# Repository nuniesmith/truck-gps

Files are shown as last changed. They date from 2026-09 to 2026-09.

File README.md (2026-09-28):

# Truck GPS mount and controller

A parametric Garmin OTR620 mount for the upper cubby of a **2022 Volvo VNL 860**, printed on an **Ender 3 Neo with a 220 × 220 mm bed**.

**Current print checkpoint: [v0.6 caliper fit tests](src/stl/v0.6/README.md).** The user confirmed a **170 mm clear inside width, 98 mm front height and 80 mm height below the rear notch**, plus cased AirPods measuring **64 x 49 x 24 mm**. Four updated coupons test these dimensions. **The v0.5 full insert and rear electronics layout need revision before printing:** its fan and carrier exceed the newly confirmed rear height. The complete electronics prototype remains archived in [v0.5](src/stl/v0.5/README.md).

The controller plan is now **Pico first, Linux Zero later**. This supersedes the earlier Zero-only control plan. `src/pi/` remains a simulation-only Python package; it has no live GPIO, Pico firmware, working power distribution or telemetry integration.

## Start here

- [Current fit coupons and measurement review](src/stl/v0.6/README.md)
- [Previous electronics prototype and assembly](src/stl/v0.5/README.md)
- [Hardware choices, fan variant and power architecture](docs/hardware-v0.5.md)
- [Complete staged parts list](docs/parts-list.md)
- [Current tasks and measurements](docs/todo.md)
- [Pico and future Linux implementation plan](docs/pi-setup.md)
- [Run the existing controller simulation](src/pi/README.md)
- [Recorded v0.2 truck tests](docs/fit-test-v0.2.md)
- [Conversation archive](docs/chats.md) and [v0.5 decision record](docs/decisions-v0.5.md)

## What has been checked physically

The user reports that the original front test frame fits, the 7 mm dash-bolt shank passage works, and the AirPods Pro 3 with Latercase fit snugly in the collar. The earlier **rear +10 mm** correction was implemented in v0.4/v0.5, but is now superseded by the confirmed **80 mm height below the rear notch**. The v0.6 gauges use the new measurements and have not yet been physically tested. The original bolt-head pocket was too tight; the current **10.8 mm** pocket remains a trial until a sizing coupon is selected. The existing ball mount will be removed. The rubber cubby liner may be removed if needed for seating.

No physical fit is claimed for the new fan, complete Pico stack, ESR recess, control pod, future Zero module, GPS bezel or angled GPS cable. Mesh validity and nominal CAD clearance are distinct from these tests.

## Mechanical layout

The following describes the previous prototype; its rear packing is pending revision.

| Area | v0.5 provision |
|---|---|
| Main cubby | Fan on the driver's-view left; Pico/Freenove carrier on the right; existing dash-bolt columns retained |
| GPS front | Removable gasketed faceplate using four ordered M2 × 6 screws and plain nuts |
| Ventilation | Lower speaker/intake slots and a matching-style upper exhaust row; microphone clearance retained |
| AirPods side | Tested collar section, front facing up at 45°, with bottom USB-C cable access |
| PopSocket side | Flat storage face with a trial recessed ESR target ring; no charging |
| Shelf underside | Removable future Pi Zero 2 W module and separate universal power module |
| Optional left pod | Replaceable blank front for a selected OLED and switches |
| Power inlet | Replaceable blank panel; USB-C hardware still to be selected |

The upper border cannot accommodate the full lower-slot height. Its shorter vents and shallow fan plenum need an airflow/noise test. No cooling performance is guaranteed by the CAD. The optional control pod and populated shelf need a radio/trim clearance check in the truck.

## Controllers and power

The **Pico 2 WH** will handle the local fan, temperature sensor, dim blue LEDs, buttons and display. The future **Pi Zero 2 W**, running a full OS, can provide network access, logging, maps and other services. Basic cooling must continue if that computer or its network connection fails.

The Pico sends control signals; a separate protected power circuit supplies the load current. Initially keep the Garmin on its supplied/approved power arrangement and power the accessories separately. The earlier 5 V / 1 A GPS estimate is unverified. A combined USB-C input requires a selected sink/PD design, rated regulation, protected outputs and proper USB-C charging-port behavior. A bare socket or splitter is insufficient. The Linux computer also needs a defined shutdown/power-hold arrangement.

**Fan selection:** use the exact **NF-A4x20 5V PWM** model. The recently linked B072Q3CMRW is the three-pin 5 V variant; the earlier B071W93333 is 12 V PWM. The final user decision is four-pin PWM at 5 V. See the [manufacturer-backed connection plan](docs/hardware-v0.5.md#fan-wiring-and-behavior).

## Revision history

| Directory | Role |
|---|---|
| [v0.1](src/stl/v0.1) | First Claude design and tests |
| [v0.2](src/stl/v0.2) | Rubber pads and accessory shelf; user's first reported fit tests |
| [v0.3](src/stl/v0.3) | ChatGPT V3.1 faceplate, M2 hardware and coupons |
| [v0.4](src/stl/v0.4) | Measured rear +10 mm, bolt-head coupons and wired AirPods shelf |
| [v0.5](src/stl/v0.5) | Previous electronics prototype; rear height superseded |
| [v0.6](src/stl/v0.6) | Four caliper-based fit coupons; full enclosure revision pending |

Older revisions and transcripts are preserved. The `v0.3` folder contains the CAD revision named V3.1; older `src/v0.x` paths and repository names in the archive are historical.

## Future software

The Linux simulation in `src/pi/` implements fan hysteresis, auto/boost policy, LED requests, typed sensor faults and text/JSON status. It does not operate physical hardware. A Pico firmware project and a bounded Pico-to-Pi protocol remain to be implemented. See [the implementation plan](docs/pi-setup.md).

Later goals include truck Wi-Fi/Starlink connectivity, a private Tailscale connection to a home display, trip history and a map. A live Garmin position interface has not been established; a separate GNSS receiver may be needed. Neither selected board has built-in GNSS. The existing [TomTom](docs/tomtom-api.md) and [Google Maps](docs/google-maps-api.md) notes are planning references; recheck terms and pricing when implementing those services.

Repository: [nuniesmith/truck-gps](https://github.com/nuniesmith/truck-gps).

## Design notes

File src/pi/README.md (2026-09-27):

# Truck GPS controller: simulation milestone

> **v0.5 architecture update:** the Pico 2 WH is now planned for local hardware control; a Pi Zero 2 W will add Linux services later. This package remains a simulation and is not Pico firmware. Follow [the current implementation plan](../../docs/pi-setup.md) and [hardware decisions](../../docs/hardware-v0.5.md). Earlier Pi-only hardware suggestions below are superseded.

Runnable control logic for the planned **Raspberry Pi Zero 2 W / Raspberry Pi OS Lite** installation. Requires Python **3.11 or newer** and has no runtime dependencies outside the standard library. GPIO, physical sensors, fan PWM, buttons, OLED, GPS power switching and telemetry are **not implemented**. The only supported mode is `simulate`.

## Run now, without Pi hardware

From the repository root:

```sh
cd src/pi
python3 -m truck_gps --config config.example.toml
python3 -m truck_gps --config config.example.toml --format json
python3 -m unittest discover -s tests -v
```

The built-in 12-sample demo completes immediately. Each sample advances a virtual clock by five seconds. Use `--realtime` to pace samples in wall-clock time, or `--realtime --loop` for a continuous demonstration. The timestamps still represent **scenario time**, not measured sensor acquisition time. Ctrl+C or SIGTERM interrupts the wait and exits cleanly.

For an installed command, use a virtual environment:

```sh
python3 -m venv .venv
.venv/bin/python -m pip install .
.venv/bin/truck-gps --format json
```

Building the package requires setuptools; pip may download the build tooling. No Raspberry Pi or GPIO packages are needed for simulation. Keep local settings in `config.local.toml` (ignored by git); do not put credentials in configuration files committed to the repository.

## Control behavior

These values are **bench starting settings**, not validated GPS/charger protection limits. Adjust only after choosing sensor placement and measuring the actual installation.

| Condition | Requested fan duty with the example configuration |
|---|---|
| Fresh startup, valid temperature below 35°C | 0% |
| Temperature reaches 35°C | 30% |
| Temperature rises from 35°C to 45°C | Linear increase from 30% to 100% |
| Temperature at or above 45°C | 100% |
| Active fan cools below 35°C but remains above 32°C | Hold 30% |
| Temperature reaches 32°C or lower | 0% |
| Manual `boost` | 100% |
| Missing, invalid, wrong-ID or stale sensor reading | 100% and an explicit fault |

A reading becomes stale when its age **exceeds** 15 seconds. A future or invalid timestamp is a fault. Sensor faults take priority over manual mode. There is deliberately no manual force-off mode. After a fault or boost, automatic control keeps the fan active until the stop threshold is reached. Restarting the process resets the hysteresis latch and command state; it does not preserve settings from earlier runs.

The 30% minimum is a requested value, not a verified starting or sustainable fan speed. Startup kick, calibrated minimum duty, electrical fallback and measured RPM remain hardware work. A software request for full cooling cannot guarantee cooling if the fan supply or controller fails.

LEDs default off with a stored brightness of 5%. Turning them off preserves the setting. LED commands do not affect fan decisions. `--led-on`, `--led-brightness 8` and `--fan-mode boost` set **initial** commands; later scenario events can change them. Brightness alone does not enable the LEDs. In particular, the built-in demo intentionally changes LED and fan modes.

## Custom scenarios

```sh
python3 -m truck_gps --scenario scenarios/example.json --format json
```

A scenario is a JSON array. Each row must contain exactly one sample source:

- `"temperature_c": 40` for a valid numeric reading, or `null` for a missing sensor.
- `"error": "disconnected"` for a reported sensor fault.
- `"w1_text": "aa YES\naa t=35000"` to exercise parsing of a captured Linux 1-Wire text sample.

Optional fields are `age_s` (default 0), `fan_mode` (`auto` or `boost`), `led_enabled` (boolean) and `led_brightness_pct` (0–100). Command changes persist into following rows until changed again. A repeated scenario retains command and hysteresis state across the loop boundary. Temperature/source and age apply to their own row only. Unknown keys, non-finite numbers, invalid commands and malformed configuration are rejected before the simulation starts. Out-of-range finite temperatures are accepted as scenario inputs and become controller faults.

The 1-Wire parser checks the kernel's `YES` CRC result marker and temperature format. It does not independently calculate CRC or read `/sys`. There are no device reads or retry loops yet; bounded acquisition and freshness tracking must be implemented for live sensors.

## Output and verification

Text output labels all values as requests. `--format json` emits one status object per line to stdout, with logs on stderr. `simulated` is always `true`; `fan_rpm` and `gps_power` are always `null` (unknown). No RPM, GPS state or power feedback is invented. `sensor_id` identifies the configured expected sensor, not necessarily a connected device.

All 21 tests passed on Linux with Python 3.12.14. Wheel building, installation into a clean virtual environment and the installed CLI demo also passed. Tests cover the fan curve and hysteresis, fault priority/recovery, stale boundaries, malformed readings, configuration validation, LED independence, restart state, CLI output and SIGTERM handling. They verify software decisions only. No physical fan, sensor, OLED, GPIO timing or Raspberry Pi installation has been tested.

## Optional Linux service example

[`systemd/truck-gps-sim.service`](systemd/truck-gps-sim.service) is a **simulation-only template**, not a production cooling service. It loops the demo and logs JSON to the journal. To use it later, install the package in `/opt/truck-gps/.venv`, copy settings to `/etc/truck-gps/config.toml`, create a dedicated `truck-gps` service account with read access to those paths, and install the unit in `/etc/systemd/system/`. Then reload systemd and start `truck-gps-sim.service`; enable boot startup only if wanted. Use `journalctl -u truck-gps-sim.service` to inspect output.

The template deliberately denies device access. Do not adapt it for live hardware merely by removing that restriction: implement and test the GPIO/sensor adapters and their permissions first. Neither this unit nor a restart policy provides an electrical cooling fallback or a Linux power-hold/shutdown circuit.

## Next implementation work

1. Record the installed Pi OS/Python versions and verify hardware PWM support for that board/OS.
2. Select the fan interface and validate the protected 5 V branch, PWM waveform and boot/crash state on the bench.
3. Add identified live temperature sensors with bounded acquisition and stale-data handling independent of control ticks.
4. Add fan/LED adapters, debounced buttons and optional tach feedback, then an OLED using shared state.
5. Validate systemd permissions, restart and power-hold/shutdown behavior before installation in the truck.
6. Add independent GNSS logging, Tailscale and the home map later.

See [the hardware and first-boot plan](../../docs/pi-setup.md) and [the project tasks](../../docs/todo.md). The Garmin initially stays on its supplied power arrangement. v0.4 CAD awaits fit results and actual component measurements.

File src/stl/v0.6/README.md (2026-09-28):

# v0.6 — caliper fit checkpoint

**Print these four test pieces next. This is not a complete enclosure revision.**
The confirmed inside dimensions supersede the v0.4/v0.5 rear +10 mm correction.
Do not print the v0.5 full insert, carrier or packing test for the newly measured cubby.
The existing electronics layout needs a separate revision after these gauges fit.

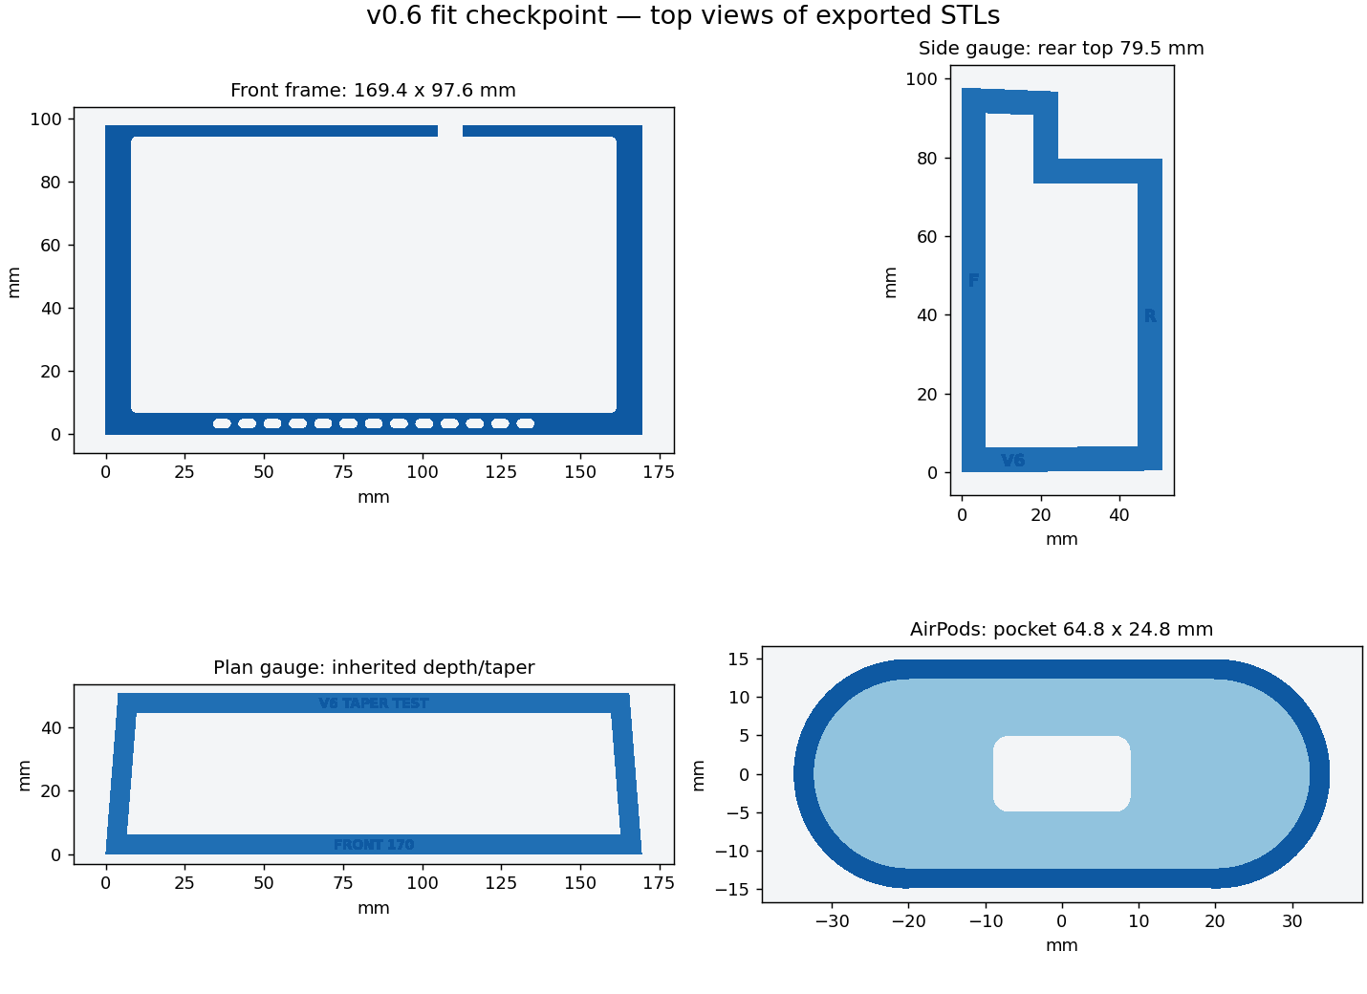
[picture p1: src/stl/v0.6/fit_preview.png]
Top views of exported test pieces


## Confirmed user measurements

Recorded 2026-09-27 (America/New_York), from the caliper sketch and follow-up replies.

| Feature | Measurement | Coupon geometry |
|---|---:|---:|
| Clear inside front width | 170 mm | 169.4 mm, 0.3 mm clearance each side |
| Front opening height | 98 mm | 97.6 mm, 0.4 mm top clearance |
| Height below rear notch | 80 mm | Rear top 79.5 mm above front-floor datum |
| AirPods + Latercase width | 64 mm | Pocket width 64.8 mm |
| AirPods + Latercase thickness | 24 mm | Pocket thickness 24.8 mm |
| AirPods + Latercase height | 49 mm | Reference for next shelf layout; collar height stays 12 mm |

The notebook's 80 mm label is a height, not depth. The user explicitly confirmed
170 mm is the inside width. These are reported measurements, not measurements
independently taken by the CAD author.

The old width input was 165.1 mm, giving a 164.5 mm printed frame. The new frame
is 4.9 mm wider. Do not scale the old STLs in the slicer: that would change the
GPS pocket, bolt holes and component footprints too.

## Print and test

Print at **100% scale**, in the supplied flat orientation. Each piece fits a
220 x 220 mm bed with a nominal 10 mm brim allowance per side. No designed
unsupported roofs occur in these coupons; inspect your slicer preview.

1. **front_frame.stl** — 169.4 x 97.6 x 4 mm. Check seating across the full
   opening without forcing. Its GPS pocket is the inherited nominal
   153.8 x 87.8 mm with 2 mm corners, microphone notch and lower grille.
   This checks the cubby face, not the actual GPS, faceplate screws or top vents.
2. **side_gauge.stl** — 50.8 mm deep x 97.6 mm high, 3 mm thick plus labels.
   The **F** edge faces the driver; **R** goes to the back. Seat the bottom on
   the same floor/liner datum used for the measurement. The notch starts
   24.4 mm behind the front; the rear top is flat at 79.5 mm. Check each side
   of the cubby independently, including the rubber lip. Record whether the
   liner is in or out; do not pull a binding gauge into place with bolts.
3. **plan_gauge.stl** — checks front width, 50.8 mm depth and the inherited
   4 mm-per-side taper (161.4 mm wide at the back). FRONT faces the driver.
   This taper is still a photo-based assumption; report any side interference.
4. **airpods_charge_test.stl** — enlarged 64.8 x 24.8 mm pocket, 12 mm collar,
   2.5 mm floor. Compare against the previously snug collar. Test retention,
   removal and your actual angled cable through the provisional 18 x 10 mm
   bottom opening. A physical pass is needed: the caliper maximum may occur
   above the section gripped by this shallow collar.

The 25.4 mm bar depth, 50.8 mm total depth, 1 mm upper-roof drop and 0.5 mm
rear-floor rise are inherited assumptions, not new measurements. Unlike v0.5,
the rear ceiling in this test is flat: the single confirmed 80 mm height does
not establish an underside slope. The gauge is intended to resolve this fit.

## Electronics review

The old layout does not fit the new height as drawn:

| v0.5 feature | Highest Y above front floor | Comparison with 80 mm rear clearance |
|---|---:|---|
| Fan body/pads | 82.0 mm | 2.0 mm too high |
| Rear carrier rectangle | 86.2 mm | 6.2 mm too high |
| Upper carrier boss envelope | 86.0 mm | 6.0 mm too high |
| Freenove PCB outline | 76.0 mm | Outline alone is below ceiling; mounting/wires still need rework |

The fan remains 40 x 40 x 20 mm (22 mm with pads), four-pin **5 V PWM**.
The control architecture remains Pico 2 WH/Freenove first, Pi Zero 2 W later.
A possible next layout lowers the fan center from Y=62 to Y=56 and the PCB
origin from Y=19 to Y=12; these are proposals only, not validated mounts.
The carrier, bosses, plenum, wiring and shell must be redesigned together and
checked against the actual stepped cubby envelope. Nothing in this checkpoint
claims that the complete assembly or airflow is validated.

## Reproduce

```sh
python export_models.py
python validate_meshes.py
```

OpenSCAD is required for exports and NumPy for validation. `mesh_checks.json`
records watertight oriented edges, triangle validity, connected components and
bed bounds. It does not certify strength, cooling, physical fit or GPS retention.
`fit_check.scad` is standalone; it deliberately provides no full insert export.

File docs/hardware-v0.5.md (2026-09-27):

# v0.5 hardware decisions and electrical plan

Updated 2026-09-27. This is a mechanical prototype and an electrical design plan. There is no completed power-distribution circuit or Pico firmware in this revision. [Print instructions](../src/stl/v0.5/README.md) · [Parts](parts-list.md) · [Software plan](pi-setup.md)

## Selected parts

| Function | Selection | CAD basis / status |
|---|---|---|
| Fan | **Noctua NF-A4x20 5V PWM, four-pin** | 40 × 40 × 20 mm body; **22 mm with pads**; **32 × 32 mm** screw pattern |
| Local controller | **Raspberry Pi Pico 2 WH** | Header-equipped Pico 2 W; mounted using the Freenove board |
| Breakout | **Freenove FNK0081 / CB8101** | **63 × 57 mm**, **58 × 52 mm** mounting pattern from its mechanical drawing |
| Future Linux computer | **Raspberry Pi Zero 2 W** | 65 × 30 mm board; 58 × 23 mm mounting pattern; under the AirPods side of the shelf |
| PopSocket target | **ESR HaloLock Universal Ring 360**, linked ASIN B09BZ17JM7 | Ordered; exact ring and adhesive thickness not measured. CAD recess is a trial |
| Faceplate | Four **M2 × 6 mm** machine screws with plain M2 nuts | Ordered; test actual screw heads and nuts in the supplied coupons |

The final fan choice supersedes both earlier Amazon links: **B071W93333 is the 12 V PWM version; B072Q3CMRW is the three-pin 5 V version.** Neither is the final requested combination. Order by the exact name **NF-A4x20 5V PWM** and verify four pins and 5 V on the label. No unverified replacement ASIN is supplied here.

The other user-supplied links were [Pico 2 WH](https://www.amazon.ca/gp/product/B0FC2QLC17), [Freenove breakout](https://www.amazon.ca/gp/product/B0BFB53Y2N), and [ESR ring](https://www.amazon.ca/dp/B09BZ17JM7). Retail package dimensions are not final part measurements.

## Physical arrangement

- **Inside the cubby:** fan on the driver's-view left, Freenove/Pico assembly on the right. The breakout attaches to a removable rear carrier. Existing dash bolt columns and the shelf's two mounting tongues remain.
- **Under the shelf:** a removable Zero 2 W module on the AirPods side and a separate module for a future selected power board on the PopSocket side. The power module has tie slots and a replaceable blank inlet panel; it does not assume a particular PD/regulator board.
- **Beside the front frame:** an optional control pod with a replaceable blank face for the eventual display and switches. Its outside edge is 42 mm left of the original insert. Verify clearance to truck trim before printing the whole pod.
- **AirPods:** retain the successful collar section and upward-facing 45° orientation, with the v0.4 bottom cable opening. No wireless charger is included.
- **PopSocket:** remove the raised oval rim and use a shallow circular recess for the ESR target. The PopSocket supplies the magnetic attraction. This is storage, with no charging electronics.

The Freenove PCB dimensions are verified, but its assembled height with the Pico, headers and wiring is not. The CAD reserves **21 mm forward from the breakout PCB back face**. Measure that complete stack. Programming USB access is a bench operation with the carrier removed; a plugged-in USB cable has not been shown to fit beside the board inside the cubby.

The future Zero module reserves a board/component envelope, not every header, heatsink or cable variant. Orient and measure connectors before installing it. Neither the Pico nor the Zero includes a GNSS receiver. Live navigation data from the Garmin has not been established; the Linux mapping project may require a separate receiver.

## Airflow and lighting

The proposed fan direction draws from the rear electronics bay and blows forward into a shallow plenum that turns upward. Lower sound slots admit air; the new upper slots exhaust it. The upper slots share the lower grille's capsule shape and pitch but are shorter because the upper frame is thin. Slots around the microphone are omitted.

This is a restricted path: the fan has about **2.4 mm** rear intake clearance; the upper riser narrows to **1.8 mm** in depth. These are CAD clearances, not proof of useful cooling. Bench-test temperature, airflow, whistling and audible GPS instructions. Speaker and fan air share the lower bay, so acoustic isolation is not claimed. If the flow is inadequate, use a larger external vent/plenum or relocate the fan before relying on cooling. The shell is not airtight, and small screw-access openings allow leakage.

Two dim blue LEDs can use the loose printed carrier and the rear carrier's tie slots. Position the LEDs against an internal surface to avoid direct glare; add current limiting and a suitable driver. The carrier's 3.3 mm bores are trial fits for nominal 3 mm LEDs. Secure insulated wires away from the impeller and the microphone path. A separate tie provision can retain a temperature-probe lead; probe shape is not finalized.

## Power architecture

The **Pico makes control decisions**. A separate rated circuit supplies the GPS, fan, LEDs, charging port and future Zero. The Freenove board is a GPIO breakout, not a multi-amp power-distribution device. Do not route accessory load current through GPIO or the Pico's 3.3 V rail.

For initial use, retain the Garmin's supplied/approved power arrangement and give the accessories a separate regulated 5 V supply. Verify the GPS and adapter labels and actual demand; **5 V / 1 A is not a confirmed GPS rating**.

For a later single-input system, select the USB-C sink/PD hardware, converter, protected outputs and connectors together. A plain USB-C socket or splitter is insufficient. USB-C charging outputs need the appropriate source/CC behavior for C-to-C cables. Match the negotiated input, output current, protection and thermal capacity to measured loads. Do not assume all USB-C PD sources offer 12 V.

The future power module's empty space is about **64 × 38 × 15 mm**, reduced by posts and the inlet bosses. Select a circuit that actually fits or replace that module. A protected external power unit remains an option without changing the GPS insert.

A capacitor can help with supply transients; it does not replace a power supply or implement lighting control. A Linux shutdown needs a defined hold-up/power-latch arrangement if ignition or a master switch removes its supply. The Pico can request shutdown and operate a properly rated load switch after an acknowledgment, but power switching hardware is still to be designed. Prevent USB/programming-supply backfeed using the Pico manufacturer's power arrangements.

## Fan wiring and behavior

| Pin | Noctua wire colour | Planned function |
|---|---|---|
| 1 | Black | Common ground |
| 2 | Yellow | Regulated protected 5 V branch |
| 3 | Green | Tachometer input with a suitable 3.3 V interface |
| 4 | Blue | PWM signal through a compatible driver/interface |

Keep fan power continuous during speed control. Nominal maximum fan load is 0.1 A at 5 V. Verify connector orientation; other fan variants have different wire colours.

Use the Pico's hardware PWM at a 25 kHz target. Noctua's white paper recommends a CMOS-style driving circuit and does **not** recommend open-collector PWM drive. Its PWM input has an internal pull-up, which must be checked for compatibility with the Pico's 3.3 V pins and unpowered state. Select and bench-test the interface rather than copying a generic PC-fan diagram. The tach output is a separate open-collector signal, with two pulses per revolution.

With PWM disconnected, the fan normally runs at full speed. That does not cover a controller fault that holds PWM low. Verify boot, reset, disconnected sensor, stalled fan, missing host and driver faults. A software watchdog alone does not establish a hardware fail-safe.

## Sources checked for this revision

- [Noctua NF-A4x20 5V PWM specifications](https://www.noctua.at/en/products/nf-a4x20-5v-pwm/specifications)
- [Noctua three-pin 5 V specifications](https://www.noctua.at/en/products/nf-a4x20-5v/specifications)
- [Noctua PWM specification white paper](https://noctua.at/pub/media/wysiwyg/Noctua_PWM_specifications_white_paper.pdf)
- [Raspberry Pi Pico 2 W datasheet](https://datasheets.raspberrypi.com/picow/pico-2-w-datasheet.pdf)
- [Freenove FNK0081 product](https://store.freenove.com/products/fnk0081) and [CB8101 drawing v1.1](https://github.com/Freenove/Freenove_Breakout_Board_for_Raspberry_Pi_Pico/blob/master/CB8101_mechanical-drawing_v1.1_20240326.pdf)
- [Raspberry Pi Zero 2 W](https://www.raspberrypi.com/products/raspberry-pi-zero-2-w/) and [mechanical product brief](https://datasheets.raspberrypi.com/rpizero2/raspberry-pi-zero-2-w-product-brief.pdf)
- [ESR HaloLock Universal Ring 360](https://www.esrtech.com/en-ca/products/halolock-universal-ring-360-black-2-pack)

The layout and clearances are this project's design decisions. They have not been certified by the component manufacturers or physically validated in the truck.

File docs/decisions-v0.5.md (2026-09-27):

# v0.5 request and decision record

Date: 2026-09-24. This is a concise decision record, not a reconstructed verbatim transcript of missing assistant turns. Earlier session text remains in [chats.md](chats.md).

The user asked to support a 40 × 40 × 20 mm fan, a Pico 2 WH microcontroller and, if practical, a future full-OS computer. They requested provisions for switches, a screen, temperature sensing, blue LEDs, USB-C intake/power distribution, the GPS and the future computer. The intended full-OS board is documented as Raspberry Pi Zero 2 W, distinct from the Pico.

They supplied Amazon links B071W93333, B0FC2QLC17, B0BFB53Y2N and B09BZ17JM7, asked for a flush recess for the ordered ESR ring, matching top/bottom vent styling, a faceplate and further test prints. They ordered M2 × 6 screws with nuts for the faceplate and expect the GPS in the next few weeks.

The later fan message was: “use this fan the 5v one”, linking B072Q3CMRW. That is the three-pin model. After the distinction was explained, the final user choice was: **“Yeah I want 4 pin pwm 5v”**. The active selection is therefore **Noctua NF-A4x20 5V PWM**, not either earlier incompatible fan variant.

Design decisions in this revision:

- Preserve the measured front fit, rear +10 mm, passing bolt-shank bore and snug AirPods collar section.
- Keep the head pocket, GPS envelope, ring dimensions and full electronics stack provisional until measured.
- Put the fan and Pico/Freenove inside the cubby; reserve separate shelf modules for future Zero and power circuitry.
- Keep control and inlet panels replaceable and blank until exact modules are selected.
- Use the Pico for local control and separate rated hardware for power delivery. Add Linux features later.
- Treat the airflow layout, PCB packing and screw stacks as prototypes requiring the supplied fit tests.

These choices are implemented in [v0.5](../src/stl/v0.5/README.md); the electrical circuit and firmware are not implemented by the CAD work.

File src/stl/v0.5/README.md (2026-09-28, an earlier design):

> **Fit dimensions superseded:** use the [v0.6 caliper fit checkpoint](../v0.6/README.md) next. Confirmed inside dimensions are 170 mm wide, 98 mm front height and 80 mm below the rear notch. This revision's full insert, carrier and packing test exceed the corrected rear clearance; do not print them as the current fit. Original documentation below is historical.

# v0.5 — electronics and modular shelf prototype

**Status: fit-test prototype, not the final long-print release.** The actual GPS, complete Pico/breakout stack, ESR ring and cable envelopes still need measurement. Editable source: [otr620_vnl_v0_5.scad](otr620_vnl_v0_5.scad). [Hardware decisions](../../../docs/hardware-v0.5.md) · [Parts list](../../../docs/parts-list.md)

This revision preserves the v0.4 front opening, measured rear-step rise, bolt-shank bores and successful AirPods collar section. It adds a Noctua **NF-A4x20 5V PWM** mount, a removable Freenove/Pico carrier, top vents, a trial ESR recess, an optional control pod and two removable shelf modules. The future computer is **Raspberry Pi Zero 2 W**, distinct from the Pico microcontroller.

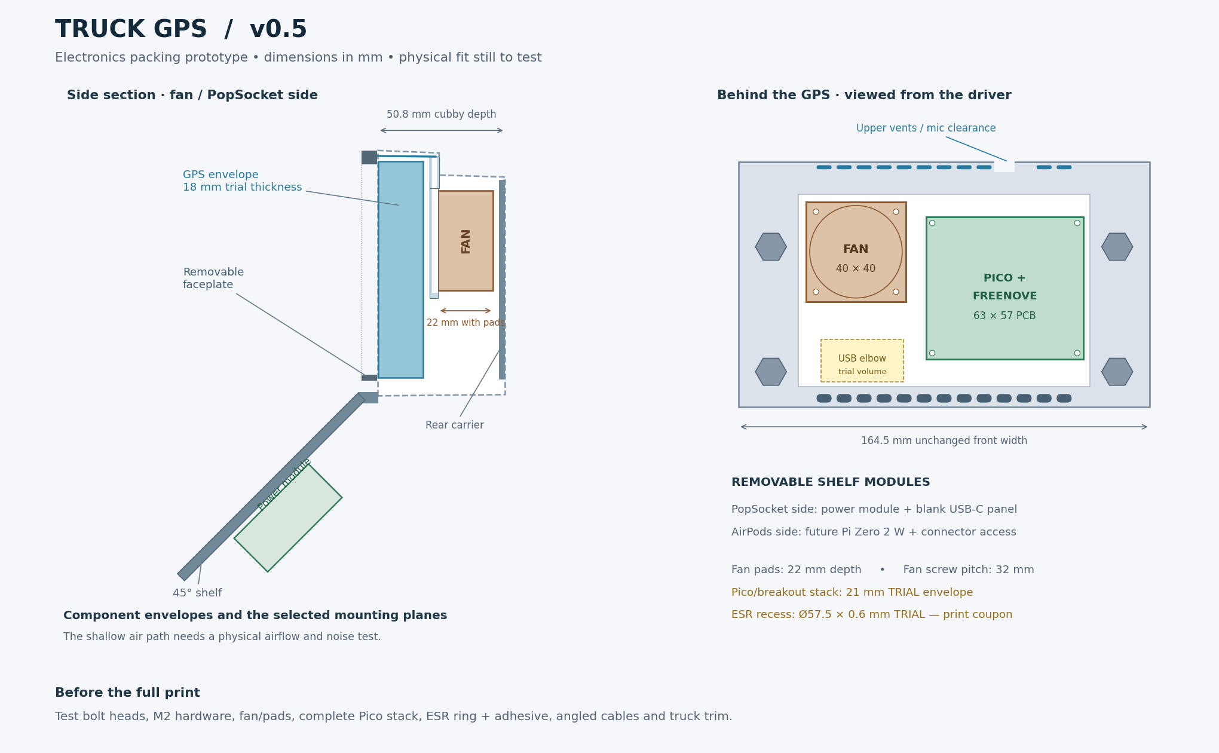
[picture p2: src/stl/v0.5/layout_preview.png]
Default component packing, with trial dimensions identified


## Print queue

Print at 100% in millimetres. These are tests, not an instruction to print all 22 files immediately.

| Order | Files | What to establish |
|---|---|---|
| 1 | `side_gauge_plus10.stl`, `bolt_head_fit_test.stl` | Confirm the measured rear rise; choose the smallest head pocket that seats the actual bolt without force. Retained unchanged from v0.4 |
| 2 | `airpods_charge_test.stl` | Confirm the tested collar with the actual angled charging cable through the bottom opening. Retained from v0.4 |
| 3 | `nut_test.stl`, `bolt_cover_test.stl` | Fit the ordered M2 nuts/screws and verify the 6 mm faceplate screw stack. Nut choices are 4.1 / 4.3 / 4.5 mm across flats, left to right |
| 4 | `fan_mount_test.stl`, `rear_carrier.stl` | Check fan hole pattern, pad stack, mounting hardware, Freenove holes and the installed Pico/header height |
| 5 | `ring_depth_test.stl` | Four **57.5 mm diameter trial recesses**, labelled 0.4 / 0.6 / 0.8 / 1.0 mm deep. Test with the adhesive included; do not glue the ring into a coupon |
| 6 | `fan_plenum_print_test.stl` | Cropped fan plenum/header in the insert's print direction; tune bridges and prove support removal before the long insert. This is not a complete airflow fixture |
| 7 | `packing_test.stl`, `control_outline_test.stl` | Check electronics packing and left-side trim space. These are alignment/layout gauges, not a substitute for the actual assembly |
| Later | Main insert, faceplate, shelf and optional module bodies/covers | Only after affected tests pass and the Garmin's fit and cable route are confirmed |

Use `packing_test` together with the known front/back cubby references. Its flat base represents the rear plane; towers extend toward the GPS. The fan tower includes its rear gap (26.8 mm total), and the Pico tower represents the provisional 29.4 mm reach from the rear plane. Neither tower is a functional electronics holder. Remove the existing ball mount for the final installation. If the rubber lip prevents seating, remove or adjust it; do not pull a distorted print into shape with bolts.

## Printable parts and OpenSCAD selectors

| STL filename | `part` selector | Role |
|---|---|---|
| `insert_v5.stl` | `insert_v5` | Main body, fan frame/plenum, top ventilation and control-pod mounting tabs |
| `faceplate_v5.stl` | `faceplate_v5` | Removable gasketed bezel, M2 × 6 hardware, matching upper vents |
| `shelf_v5.stl` | `shelf_v5` | AirPods collar, ESR trial recess and module mounting points |
| `rear_carrier.stl` | `rear_carrier` | Freenove standoffs, GPS cable opening, LED and cable tie points |
| `control_pod.stl` | `control_pod` | Optional left-side controls housing |
| `control_panel.stl` | `control_panel` | Replaceable blank for a selected screen/switch layout |
| `zero_tray.stl`, `zero_cover.stl` | `zero_tray`, `zero_cover` | Reserved future Zero 2 W module with board posts and connector windows |
| `power_tray.stl`, `power_cover.stl` | `power_tray`, `power_cover` | Universal tie-grid module; power circuitry not selected |
| `power_inlet_panel.stl` | `power_inlet_panel` | Replaceable blank for the eventual USB-C inlet/module |
| `led_carrier.stl` | `led_carrier` | Two nominal 3 mm LEDs; tie to the rear carrier after checking placement |
| `fan_plenum_print_test.stl` | `fan_plenum_print_test` | Short print to assess the new internal bridges and removable supports |
| `fan_mount_test.stl` | `fan_mount_test` | Fan screw and pad-stack test |
| `ring_depth_test.stl` | `ring_depth_test` | Four ESR recess depth tests |
| `packing_test.stl` | `packing_test` | Fan/Pico packing envelope gauge |
| `control_outline_test.stl` | `control_outline_test` | Thin control-pod trim-space gauge |
| `nut_test.stl`, `bolt_cover_test.stl` | `nut_test`, `bolt_cover_test` | M2 faceplate hardware tests |
| `side_gauge_plus10.stl` | `side_gauge` | Retained v0.4 rear +10 mm gauge |
| `bolt_head_fit_test.stl` | `bolt_head_coupon` | Retained six head-size tests |
| `airpods_charge_test.stl` | `airpods_charge_test` | Retained cased-AirPods charging-hole test |

The source is standalone. Legacy v2–v4 helpers remain for traceability; active v0.5 modules and dispatch are at the end. `part="assembly"` is a non-printing preview containing dimensional stand-ins. The top-bar, cubby, GPS and unselected electronics dimensions are assumptions except where recorded as measured.

## Dimensions that must be chosen before long prints

| Parameter | Supplied value | Basis |
|---|---:|---|
| `rear_step_raise` | 10 mm | User measured; front geometry unchanged |
| `head_af` | **10.8 mm trial** | v0.2 head was too tight; choose from the six coupons |
| `bolt_d` | 7 mm | User reports the shank fits |
| `gps_t` | 18 mm | Actual device not yet available |
| `bezel_overlap` | 1.2 mm | Must bear on housing, not glass |
| `esr_recess_d` | **57.5 mm trial** | Nominal retail diameter plus allowance; actual ring unmeasured |
| `esr_recess_depth` | **0.6 mm trial** | Select using actual ring plus adhesive |
| `fnk_stack` | **21 mm trial** | Complete mounted Pico/breakout stack not measured |
| `ap_charge_w`, `ap_charge_d` | 18 × 10 mm | Provisional angled cable clearance |

Changing `fnk_stack` changes the check envelope, not the physical cubby depth. If the actual assembly is too tall, revise its location or carrier; do not reduce the check value to hide an interference. A round 57.5 mm recess allows an ESR ring without assuming an inner diameter, but the selected depth still determines whether it sits flush. Retention strength and adhesive suitability need a physical pull test.

## Mechanical layout and limits

The front body remains **164.5 × 98 mm**. The retained faceplate spans **176.5 mm** over its mounting tabs. The optional controls pod extends the assembled width to about **212.5 mm**, but prints separately. It projects about 24 mm forward of the original front plane, plus screw heads. Its lid remains blank until the screen and switch bodies are selected. It has a rear wire opening; the final harness route into/behind the cubby must be checked with those modules and may require a separate protected pass-through.

The fan occupies the left rear bay and the Freenove/Pico the right. The GPS's nominal mounting-socket relief is retained. The 30 × 16 mm rear cable opening and a trial right-angle-plug keepout are provided. Real plug orientation, bend radius and the actual speaker/power-button positions remain to confirm.

The fan frame uses a 37 mm opening and 32 mm hole spacing. Install the fan with airflow **toward the GPS-side plenum**, then upward through the header. The shallow riser and small top slots may restrict cooling; [thermal and acoustic tests are required](../../../docs/hardware-v0.5.md#airflow-and-lighting). The microphone channel is separate at the nominal location. Do not treat the shared lower speaker/intake opening as an acoustic isolation design.

The Zero and power modules mount behind the 45° shelf. Nominal module covers stay above its lower edge; screw heads and plugged-in cables need their own clearance check. The full shelf and populated accessories may obstruct the radio below—use the packing preview/profile and truck test before final printing. No truck-trim collision certification is implied.

## Hardware and assembly

See [the bill of materials](../../../docs/parts-list.md) before buying. Faceplate M2 × 6 screws are not interchangeable with longer carrier/module screws.

1. Fit the existing dash bolts and rear washers/nuts. The shelf still shares the lower two bolts through its tongues/L-tabs.
2. Install the fan before the GPS. Trial hardware is four **M2 × 25** screws, small washers and plain nuts. Heads must fit the 4.2 mm access bores. Test the 22 mm padded stack with the fan coupon; the screw bearing seat is 1 mm ahead of the fan face. Do not over-compress pads or leave a screw touching the carrier.
3. Insert four plain M2 nuts at the front of the body's rear carrier bosses. The rear carrier uses **M2 × 8** screws with heads no larger than 4.4 mm diameter and **1.7 mm high** so they stay recessed. Tighten gently. The carrier is accessed with the insert removed from the cubby.
4. Mount the Freenove board using four **M2 × 10** screws into the carrier's rear nut pockets. The nominal stack is 1.6 mm PCB + 6 mm standoff + 2.4 mm carrier. Verify underside component and solder clearance. Do not crush the PCB or allow metal hardware to touch traces; add appropriate insulation or revise the stack if needed.
5. Fit the padded GPS after confirming all rear features and cable slack. Fit the faceplate with its four M2 × 6 screws and the tested nuts. The original 1.2 × 0.6 mm gasket groove remains; cure gasket maker away from the device. Do not clamp the display glass.
6. The optional control pod uses **two additional M2 × 6** screws into separate insert tabs. Four **M2 × 20** screws and nuts retain its blank lid. These do not share the faceplate screws.
7. Each shelf module uses four **M2 × 25** screws through its cover/body into plain nuts recessed into the shelf front. Load these nuts before assembling modules. The future Zero board uses four M2 × 8 screws and nuts in its tray, with suitable small insulating washers if required after checking the stack. The power inlet blank uses two M2 × 6 screws and nuts.
8. Add insulated ties for the LED carrier, sensor lead and cables. Keep all wiring out of the fan rotor. The empty power tray does not provide regulation, USB-C negotiation or load protection.

All screw lengths here are **nominal CAD stacks**, pending actual hardware tests. The ordered faceplate screws are confirmed as a user choice, not physically checked by this revision.

## Printing and validation

The provided STL orientations place each part on the bed. All have nominal XY room on a 220 × 220 mm bed with 10 mm brim allowance per side; slicer clips, skirts and support footprint still need inspection. Main insert: rear down/front up; the fan plenum introduces additional internal overhangs. Shelf: upright as exported, with supports under tongues and other slicer-identified overhangs. Controller/power/Zero bodies print on their back/floor; lids and coupons print flat. Nut-pocket bridges and recessed screw seats may need tuning. **The old v0.2 claim that only one strip needs support does not apply to v0.5.** Remove all support from air paths and screw entries.

Use a test material/profile first. Select the final dashboard material against actual installed temperatures and the Ender 3 Neo's capabilities. Do not assume a successful room-temperature fit establishes hot-cab durability.

`mesh_checks.json` records closed oriented edges, degenerate-triangle checks, component counts, volumes and nominal bed bounds. `geometry_checks.json` records CAD interference checks against the named dimensional stand-ins. These checks do not prove real fit, thermal performance, structural strength, connector accessibility or print success. `validate_meshes.py` requires Python and NumPy. `export_models.py` uses OpenSCAD 2021.01 or a compatible version and writes native binary STLs.

```sh
python3 export_models.py
python3 validate_meshes.py
openscad --export-format binstl -D 'part="shelf_v5"' \
  -D 'esr_recess_depth=0.8' -o shelf_custom.stl otr620_vnl_v0_5.scad
```

Use a separate output folder or remove custom STLs before running the supplied validator; its expected component counts apply to the named release files. A changed head pocket, ring depth or other parameter needs a fresh export and validation of the affected parts.

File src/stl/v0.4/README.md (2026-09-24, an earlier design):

# v0.4 — measured fit revision

These files update the V3.1 source using the reported v0.2 test results. The rear step rises **10 mm**, as measured by the owner. The front opening stays **164.5 × 98.0 mm**, the depth stays **50.8 mm**, and the floor, taper and bolt positions are retained. Earlier model directories are preserved.

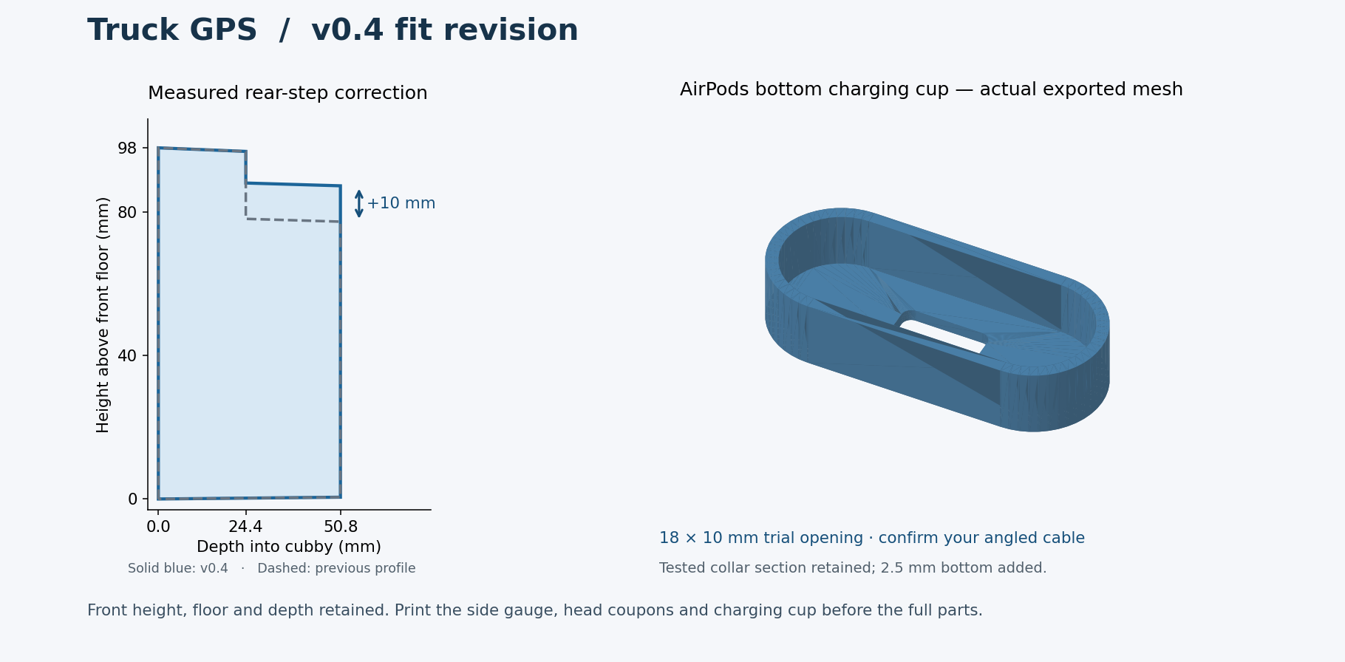
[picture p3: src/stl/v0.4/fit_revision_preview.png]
Rear-step change and exported AirPods charging cup


## Print these three small tests first

Print in millimetres at **100% scale**, in the supplied orientation. Use the same material/profile intended for the corresponding full part.

| Order | File | What to check |
|---|---|---|
| 1 | [side_gauge_plus10.stl](side_gauge_plus10.stl) | Rear lower roof/step is 10 mm higher. Keep the marked FRONT edge at the same cubby reference. Confirm both sides and seating around the rubber lip. |
| 2 | [bolt_head_fit_test.stl](bolt_head_fit_test.stl) | Six separate labeled blocks: **10.6, 10.8, 11.0, 11.4, 11.8, 12.2 mm** across flats. Choose the smallest pocket that fully seats the actual head without force and prevents rotation. All retain the successful **7 mm** shank passage. |
| 3 | [airpods_charge_test.stl](airpods_charge_test.stl) | Trial bottom cup for the AirPods with Latercase. Check snug fit, removal, port alignment and the actual USB-C plug/elbow through the bottom opening. |

The supplied full insert uses a **provisional 10.8 mm** head pocket, 0.5 mm larger than the tested v0.2 pocket. That is not a measured bolt-head size. If another coupon fits best, change `head_af` in the source and re-export the insert before the long print. If none fits, measure the actual head; enlarging beyond this range needs a wall/duct-clearance review. These shallow head coupons do not validate bolt length or the complete bearing stack.

The AirPods cup preserves the tested nominal **64.2 × 23.8 mm stadium opening**, **12 mm collar wall** and **2.5 mm walls**, and adds a **2.5 mm bottom**. Its rounded **18 × 10 mm** cable opening is a trial plug-body allowance. It is an opening for a cable, not a fixed USB-C receptacle. `ap_charge_w`, `ap_charge_d`, `ap_charge_x` and `ap_charge_z` adjust its size and alignment. Check the elbow and cable bend as well as the connector tip.

## Full parts

| File | Changes / use | Exported X × Y × Z envelope (mm) |
|---|---|---|
| [insert_trial_10p8.stl](insert_trial_10p8.stl) | Rear step +10 mm, trial head traps, retained padded GPS pocket and speaker duct | 176.5 × 98 × 55 |
| [shelf_wired_airpods.stl](shelf_wired_airpods.stl) | Snug bottom collar on the 45° shelf, broad AirPods front facing up/toward driver, bottom charging access; oval PopSocket seat retained | 164.5 × 132.763 × 97.853 |
| [faceplate.stl](faceplate.stl) | Retained V3.1 removable gasketed faceplate | 176.5 × 92 × 6.3 |

The faceplate still uses **four M2 × 6 mm screws and four plain M2 nuts**. Reuse the v0.3 nut-fit and bolt-cover coupons; their fit is not established by the v0.2 tests. External tabs extend the complete insert/faceplate width to **176.5 mm**; the successful v0.2 opening test did not check those tabs. GPS fit, bezel overlap, pads and rear cable clearance still require the actual device.

The shelf still shares the two lower dash bolts through its tongues/L-tabs. It reaches approximately **82 mm forward** and **74 mm below** the cubby floor: check the radio and controls below before printing it. The PopSocket steel-target recess remains provisional; this is storage only. The existing ball mount will be removed for installation. Remove the cubby rubber if it prevents seating; do not use the bolts to pull a binding print into shape.

All six supplied STLs fit the nominal **220 × 220 mm Ender 3 Neo bed**, including a calculated 10 mm brim allowance per side. Check the actual slicer footprint, bed clips, purge line and supports. The insert is supplied face up and the shelf upright. Review support under the insert step/tabs and the shelf tongues/angled collar; these checks do not replace slicing. No printer-specific G-code is included.

This revision provides wired AirPods access. The Pi Zero 2 W carrier, PWM fan mount, separate ventilation, OLED and switches remain for the later electronics revision.

## Source and export

[otr620_vnl_v0_4.scad](otr620_vnl_v0_4.scad) is the editable source. The default `assembly` target is a preview, not one printable object. Commands below reproduce the six deliverables with OpenSCAD 2021.01; preserve native binary export to avoid ASCII precision artifacts.

```sh
openscad --export-format binstl -D 'part="side_gauge"' -o side_gauge_plus10.stl otr620_vnl_v0_4.scad
openscad --export-format binstl -D 'part="bolt_head_coupon"' -o bolt_head_fit_test.stl otr620_vnl_v0_4.scad
openscad --export-format binstl -D 'part="airpods_charge_test"' -o airpods_charge_test.stl otr620_vnl_v0_4.scad
openscad --export-format binstl -D 'part="insert_v4"' -o insert_trial_10p8.stl otr620_vnl_v0_4.scad
openscad --export-format binstl -D 'part="shelf_v4"' -o shelf_wired_airpods.stl otr620_vnl_v0_4.scad
openscad --export-format binstl -D 'part="faceplate"' -o faceplate.stl otr620_vnl_v0_4.scad
```

## Checks performed

[mesh_checks.json](mesh_checks.json) records triangle counts, envelopes and SHA-256 checksums of these exact STLs. All have closed, consistently oriented mesh edges, positive volume and zero degenerate triangles. Each installed part/test cup/gauge is one connected component; the head coupon file intentionally contains six. Run `python3 validate_meshes.py` with NumPy installed to repeat those checks.

[geometry_checks.json](geometry_checks.json) records empty intersections for insert/shelf, insert/faceplate, the approximate AirPods stand-in and a straight charging-access prism. Intended mating surfaces are slightly separated only in the verification targets. These checks do not establish real cable-elbow clearance, print strength or physical fit. A 0.01 mm internal overlap at the retained front-tab joins removes a degenerate export triangle without changing the front outline or fastener positions.

See the [recorded fit results](https://github.com/nuniesmith/truck-gps/blob/main/docs/fit-test-v0.2.md), [parts list](https://github.com/nuniesmith/truck-gps/blob/main/docs/parts-list.md) and [remaining tasks](https://github.com/nuniesmith/truck-gps/blob/main/docs/todo.md) in the repository. The updated records are also included in the v0.4 pull request until it is merged.

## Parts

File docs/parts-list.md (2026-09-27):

# Parts list and inventory

Updated 2026-09-27 for the [v0.5 prototype](../src/stl/v0.5/README.md). [Hardware plan](hardware-v0.5.md) · [Tasks](todo.md)

**Already owned:** the large dash bolts, cased AirPods and PopSocket. The rubber roll was supplied/described earlier. **Ordered:** M2 × 6 screws with nuts, and the ESR ring. The GPS is expected in the next few weeks. Other purchase/ownership status is unconfirmed.

This list separates the initial mechanical build from later electronics. Small fastener lengths are nominal CAD stacks, pending coupons and actual parts. Inventory your stock before buying more.

## Printed parts

| Item | Installed quantity | Notes |
|---|---:|---|
| Main insert, faceplate and shelf | 1 each | v0.5 prototype; settle head/ring dimensions before full print |
| Rear Pico/Freenove carrier | 1 | Also usable as a board-hole and stack test |
| Optional control pod and blank panel | 1 each | Check left trim clearance with thin outline first |
| Power tray, cover and blank inlet panel | 1 each when needed | Circuit/module not selected; reserve space only |
| Zero tray and cover | 1 each later | Future computer, not needed for GPS-only use |
| LED carrier | 1 later | Nominal two 3 mm LEDs, bore fit to test |
| Fit coupons | Per print queue | Not installed parts; [22-file index](../src/stl/v0.5/README.md#printable-parts-and-openscad-selectors) |
| Filament | Slicer estimate + test allowance | Select final material/profile for actual dashboard temperatures and printer capability |

## Fasteners for the current CAD

All M2 screws use 0.4 mm pitch and length measured **under the head**. Use plain M2 nuts, nominal 4 mm across flats × 1.6 mm thick, unless a stack is explicitly revised. The source defaults to 4.3 mm nut pockets and 2.2 mm screw bores.

| Joint | Screws | Nuts | Notes |
|---|---|---:|---|
| Faceplate | **4 × M2 × 6** | 4 | Ordered. Pan/button head ≤ about 4 mm diameter; no extra washer in this tight stack |
| Optional control pod to insert | **2 × M2 × 6** | 2 | Separate mounting tabs; does not share faceplate screws |
| Control-pod lid | **4 × M2 × 20** | 4 | Only needed with that pod |
| Rear carrier to insert | **4 × M2 × 8** | 4 | Head ≤4.4 mm diameter and **≤1.7 mm high** for flush recess |
| Freenove to carrier | **4 × M2 × 10** | 4 | Trial 1.6 mm PCB + 6 mm posts + 2.4 mm carrier; verify solder/trace clearance |
| Fan to printed frame | **4 × M2 × 25** | 4 | Trial padded fan stack; head fits 4.2 mm access bore. Small washers at nuts, about 0.2 mm nominal thickness, to test |
| Each shelf module and lid | **4 × M2 × 25** per module | 4 per module | Two modules = eight screws/nuts; nuts load into shelf-front recesses |
| Future Zero board to tray | **4 × M2 × 8** | 4 | Check small insulating washer needs and revise screw stack if required |
| Power inlet blank | **2 × M2 × 6** | 2 | Replaceable panel; only needed with power module |

If every optional module is assembled, the nominal totals are **M2 × 6: 8; M2 × 8: 8; M2 × 10: 4; M2 × 20: 4; M2 × 25: 12; plain M2 nuts: 36**, plus spares and suitable small washers/insulation. Do not buy the whole set before confirming the fan and PCB stacks. The owned dash hardware is additional to these totals.

M2.5/M3 parts, thicker locknuts, countersunk heads and longer faceplate screws are not direct substitutes. The supplied faceplate coupons establish nut fit and screw reach; the fan coupon establishes its different stack. Included Noctua screws/anti-vibration mounts are not automatically substitutes for the M2 frame arrangement.

## Dash, GPS and accessories

| Item | Quantity | Status / selection |
|---|---:|---|
| Large dash bolts | 4 | **Owned**; shanks pass the 7 mm test bore. Head size/length/pitch still to measure |
| Matching dash nuts | 4 | Match the owned thread; do not assume M6 and 1/4-inch interchangeability |
| Dash backing washers or plate | 4 washers or suitable plate | Match wall thickness, load area and rear access |
| Rubber pads | Small sheet/roll | Existing roll first; source assumes 1 mm uncompressed with 0.7 mm side allowance |
| Compatible pad adhesive | As needed | Existing backing may suffice; cure away from GPS and test on chosen plastic |
| Front gasket | About 0.6 m allowance | Test 1.2 × 0.6 mm groove and housing contact; pre-cured gasket maker is an alternative |
| ESR HaloLock Universal Ring 360 | 1 | **Ordered**, ASIN B09BZ17JM7; measure actual OD and adhesive stack |
| Ring adhesive | Supplied or suitable alternative | Smooth clean printed seat, heat/retention test; this holds the PopSocket only |
| Garmin OTR620 | 1 | Awaiting arrival; measure housing, rear features and screen bezel |
| Garmin supply/cable | 1 set | Use supplied/approved arrangement initially; actual power requirement unresolved |
| GPS right-angle USB-C cable | 1 if needed | Measure plugged-in projection and bend direction; cable jacket needs strain relief |
| Short AirPods USB-C cable | 1 | Bottom charging hole, actual angled plug test required |
| Cable grommet/bushing | Per drilled opening | Fit actual connector bundle and panel thickness |
| Insulated ties, sleeves and labels | Small assortment | Secure cable jackets and loose carrier; keep wiring away from fan |
| Precision screwdriver, calipers | 1 each | Match actual screw drive; measure stacks rather than forcing fit |

The supplied main insert still has a **10.8 mm trial head pocket**. Coupon choices are 10.6, 10.8, 11.0, 11.4, 11.8 and 12.2 mm across flats. The shelf shares the two lower dash bolts; there is no separate large shelf fastener purchase.

## Initial controller and accessories

| Item | Quantity | What is settled / remains |
|---|---:|---|
| Pico 2 WH | 1 | Selected header-equipped microcontroller; confirm purchase |
| Freenove FNK0081 breakout | 1 | Selected footprint; verify actual board revision and full header stack |
| Noctua **NF-A4x20 5V PWM** | 1 | Final choice is **four-pin**, not either earlier incompatible variant |
| Four-conductor fan harness | 1 usable harness | Reuse supplied extension if suitable; verify connector pin order |
| Fan PWM interface | 1 circuit | Select compatible CMOS-style driver/buffer and verify powered/unpowered conditions |
| Tach interface/pull-up | 1 circuit | 3.3 V-compatible input; verify actual fan output before wiring |
| Temperature sensor | 1 initially | DS18B20 considered; exact probe/module shape and cable length unselected |
| Sensor pull-up/harness | As required | Match chosen sensor/module and 3.3 V logic; avoid duplicate onboard pull-ups |
| Blue LEDs | 2 initially | Choose LED package/brightness; loose carrier has trial 3.3 mm bores |
| LED resistors and driver | 1 set | Calculate for selected LEDs/current/supply; provide dimming and hardware off behavior |
| Front controls | Up to 4 functions | Master/shutdown request, GPS, LEDs, fan auto/boost; exact switch bodies unselected |
| OLED | 1 optional | Exact module, driver, voltage, dimensions and connector clearance unselected |
| Insulating washers/barriers | As needed | Verify PCB hole diameter, metal washer footprint and underside solder clearance |
| Regulated accessory bench supply | 1 | Rated for the measured connected loads; do not power loads from GPIO |
| Programming cable | 1 | Pico uses micro-USB; program with carrier removed and prevent backfeed |

## Later power distribution and computer

| Item | Quantity | Decision still needed |
|---|---:|---|
| USB-C sink/PD module | 1 if combining input | Source contracts, ratings, connector mounting and actual footprint |
| Regulator/converter | As required | Thermal performance and continuous/peak load budget |
| Branch protection/load switches | Per controlled load | Current rating, default state, inrush and fault behavior |
| USB-C charging-source module | 1 for AirPods | Correct C-to-C source/CC behavior; not a bare parallel receptacle |
| Input/branch harnesses, connectors | Per selected circuit | Rated wires, service loops, labels and strain relief |
| Pico/Pi power ORing/hold-up circuitry | As required | Programming backfeed prevention and controlled Linux shutdown |
| Pi Zero 2 W | 1 later | Selected future Linux board; header variant and installed height to confirm |
| microSD card and reader | 1 each if needed | Supported OS image; size/endurance appropriate for logging |
| Suitable Zero bench supply / lead | 1 | Micro-USB at the Zero; budget supply headroom per official guidance |
| External GNSS receiver | 1 if needed | Garmin live-data output has not been verified |
| Home display computer / screen | Reuse if available | Later network/map phase |

Wireless AirPods charging is deferred. No wireless charging parts are needed for this revision. The power tray is only a mechanical reserve until a real circuit is selected and measured. Source links and electrical limits are in [hardware-v0.5.md](hardware-v0.5.md).

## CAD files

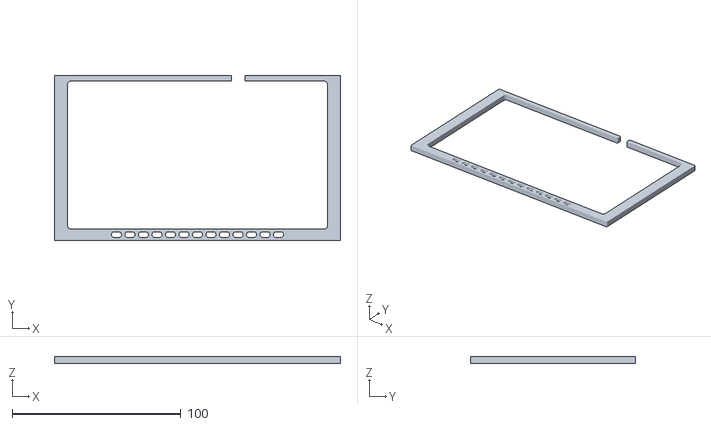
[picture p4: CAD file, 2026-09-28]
src/stl/v0.6/front_frame.stl
169.4 x 97.6 x 4.00

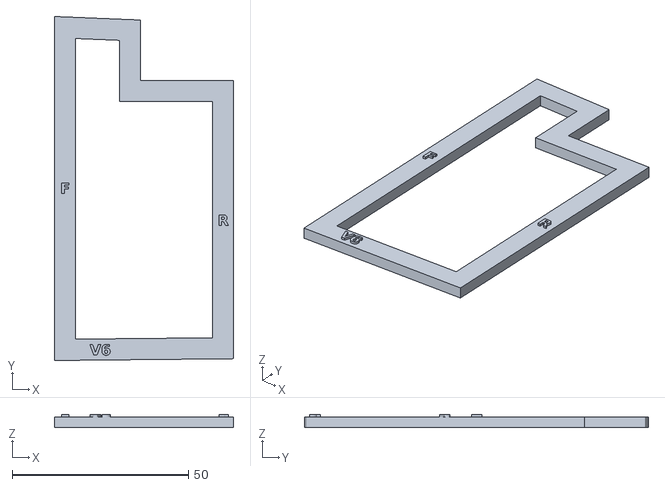
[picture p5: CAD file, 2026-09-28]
src/stl/v0.6/side_gauge.stl
50.8 x 97.6 x 3.60

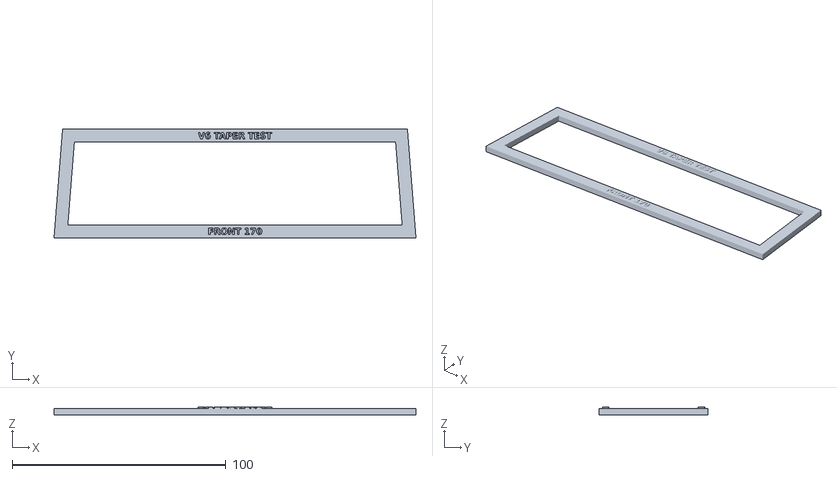
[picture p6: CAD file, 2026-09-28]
src/stl/v0.6/plan_gauge.stl
169.4 x 50.8 x 3.60

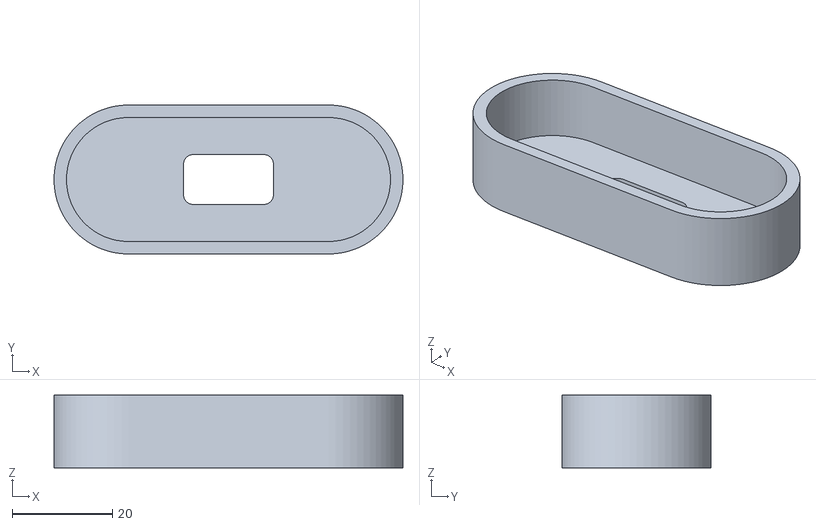
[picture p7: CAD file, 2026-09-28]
src/stl/v0.6/airpods_charge_test.stl
69.8 x 29.8 x 14.5

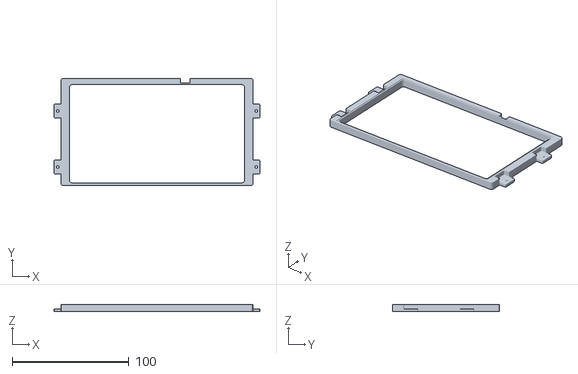
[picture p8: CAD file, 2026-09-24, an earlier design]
src/stl/v0.4/faceplate.stl
176.5 x 92.0 x 6.30

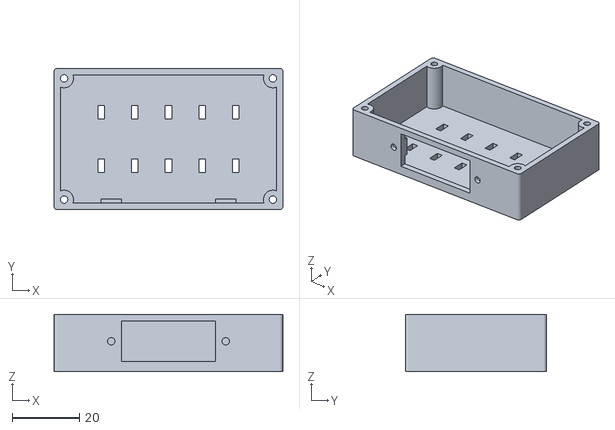
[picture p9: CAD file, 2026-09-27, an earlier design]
src/stl/v0.5/power_tray.stl
68.0 x 42.0 x 17.0

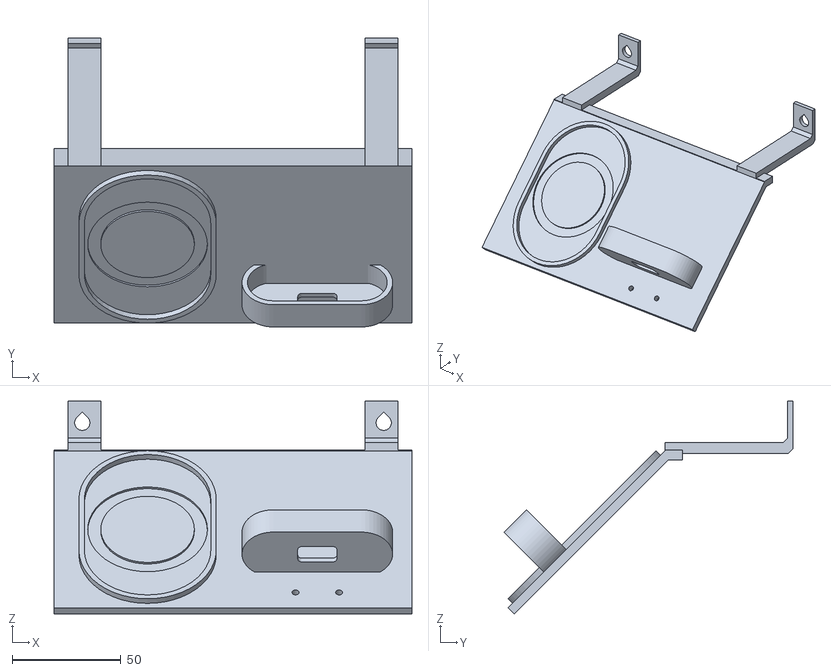
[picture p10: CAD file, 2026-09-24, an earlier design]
src/stl/v0.4/shelf_wired_airpods.stl
164.5 x 132.8 x 97.9

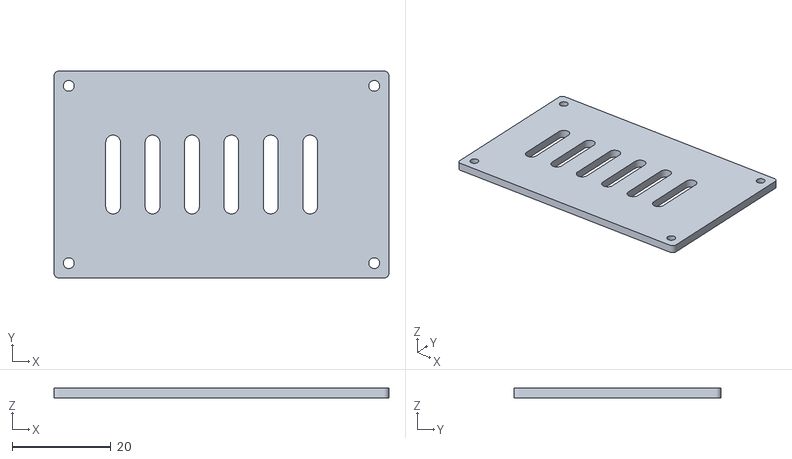
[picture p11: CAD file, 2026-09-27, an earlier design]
src/stl/v0.5/power_cover.stl
68.0 x 42.0 x 2.00

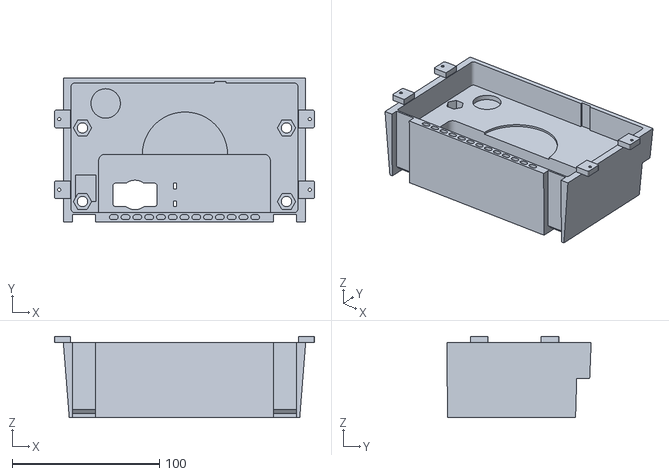
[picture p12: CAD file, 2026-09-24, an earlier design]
src/stl/v0.4/insert_trial_10p8.stl
176.5 x 98.0 x 55.0

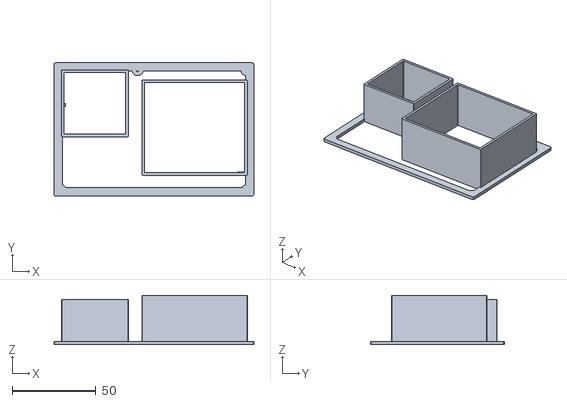
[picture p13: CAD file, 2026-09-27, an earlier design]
src/stl/v0.5/packing_test.stl
119.4 x 79.7 x 29.4

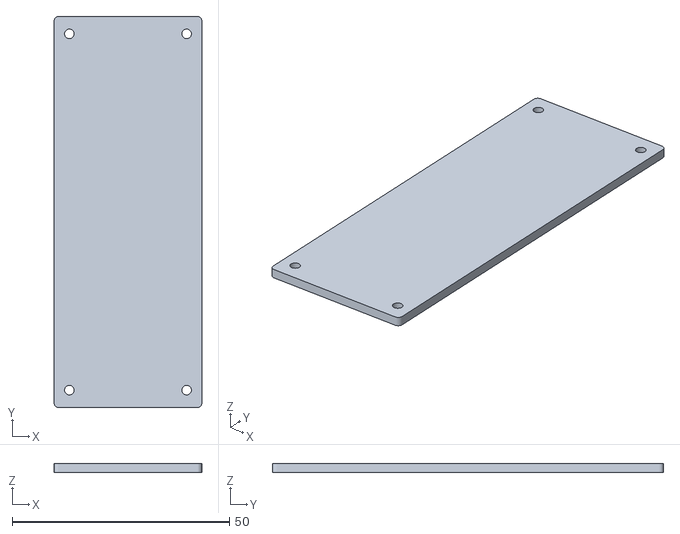
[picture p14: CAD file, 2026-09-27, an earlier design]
src/stl/v0.5/control_panel.stl
34.0 x 90.0 x 2.00

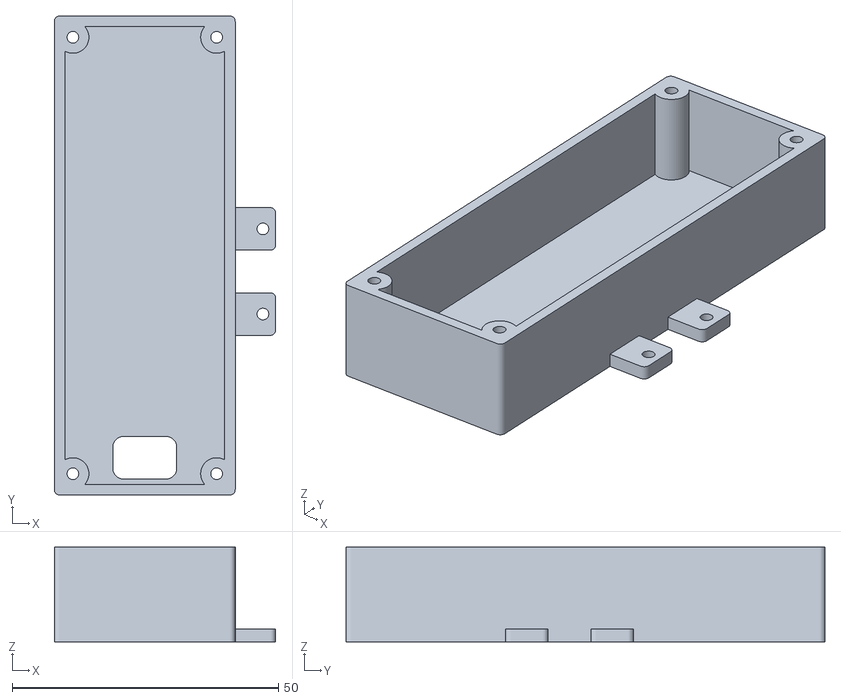
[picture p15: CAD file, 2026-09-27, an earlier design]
src/stl/v0.5/control_pod.stl
41.6 x 90.0 x 17.8

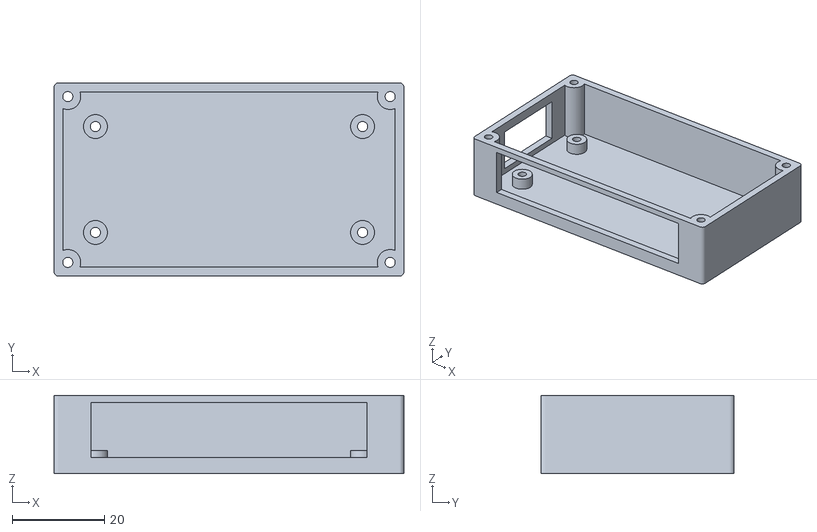
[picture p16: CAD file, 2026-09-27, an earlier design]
src/stl/v0.5/zero_tray.stl
76.0 x 42.0 x 17.0

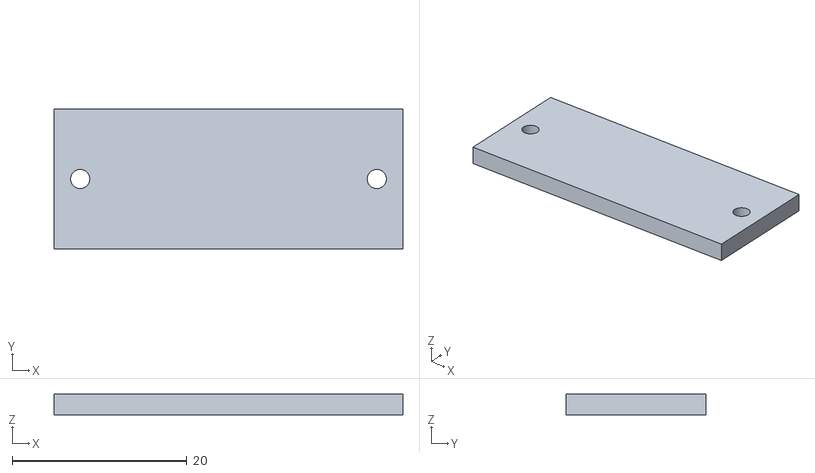
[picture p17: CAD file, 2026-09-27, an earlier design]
src/stl/v0.5/power_inlet_panel.stl
40.0 x 16.0 x 2.40

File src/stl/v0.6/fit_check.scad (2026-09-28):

// v0.6 FIT CHECKPOINT ONLY. No full enclosure/electronics mounting export.
// User caliper measurements confirmed 2026-09-27 America/New_York.
// Cubby: clear inside width 170, front height 98, height below rear notch 80.
// AirPods including Latercase: width 64, height 49, thickness 24.
// Dimensions in mm. Print at 100%. See README.md before using older parts.
part="front_frame";
$fn=64;
open_w=170;
open_h=98;
rear_h=80;
side_clear=0.3;
top_clear=0.4;
rear_clear=0.5;
front_w=open_w-2*side_clear;
front_h=open_h-top_clear;
rear_top=rear_h-rear_clear;
// These depths/tapers are inherited assumptions, NOT new caliper measurements.
cubby_d=50.8;
bar_depth=25.4;
bar_gap=1;
side_taper=4;
front_roof_drop=1;
floor_rise=0.5;
// Flat rear ceiling tests the reported 80 mm height; old +10 mm is removed.
gps_w=152.4;
gps_h=86.4;
gps_side_gap=0.7;
gps_corner=2;
chin=6.6;
pocket_w=gps_w+2*gps_side_gap;
pocket_h=gps_h+2*gps_side_gap;
pocket_x=(front_w-pocket_w)/2;
mic_x=pocket_x+gps_side_gap+100.4;
ap_w=64;
ap_h=49;
ap_d=24;
ap_clear=0.4;
ap_wall=2.5;
ap_floor=2.5;
ap_collar=12;
gauge_t=3;
assert(front_w+20<=220 && front_h+20<=220,"Bed footprint exceeded");
assert(chin+pocket_h<front_h,"GPS pocket exceeds frame");
assert(rear_top<front_h-front_roof_drop,"Notch must remain below front roof");
module rounded_rect(w,h,r){
 hull() for(x=[r,w-r],y=[r,h-r]) translate([x,y]) circle(r=r);
}
module capsule(w,h){
 hull() for(x=[-(w-h)/2,(w-h)/2]) translate([x,0]) circle(d=h);
}
module rim(t=6){difference(){children();offset(delta=-t) children();}}
module label(s,x,y){
 translate([x,y,gauge_t-0.01]) linear_extrude(0.61)
 text(s,size=3,font="DejaVu Sans:style=Bold",halign="center",valign="center");
}
module front_frame(){
 // Flat 4 mm slice checks the cubby opening and nominal GPS pocket only.
 // No faceplate tabs, bolt seats, top exhaust or actual GPS feature validation.
 linear_extrude(4) difference(){
  square([front_w,front_h]);
  translate([pocket_x,chin]) rounded_rect(pocket_w,pocket_h,gps_corner);
  translate([mic_x-4,chin+pocket_h-0.5]) square([8,front_h]);
  for(i=[0:12]) translate([front_w/2-48+i*8,3.4]) capsule(6,3.4);
 }
}
module side_gauge(){
 // Flat XY print: X is cubby depth, Y is height. FRONT is the X=0 edge.
 linear_extrude(gauge_t) rim() polygon([
  [0,0],[0,front_h],[bar_depth-bar_gap,front_h-front_roof_drop],
  [bar_depth-bar_gap,rear_top],[cubby_d,rear_top],[cubby_d,floor_rise]
 ]);
 label("F",3,front_h/2);
 label("V6",13,3);
 label("R",cubby_d-3,rear_top/2);
}
module plan_gauge(){
 linear_extrude(gauge_t) rim() polygon([
  [0,0],[front_w,0],[front_w-side_taper,cubby_d],[side_taper,cubby_d]
 ]);
 label("FRONT 170",front_w/2,3);
 label("V6 TAPER TEST",front_w/2,cubby_d-3);
}
module airpods_charge_test(){
 difference(){
  linear_extrude(ap_floor+ap_collar) offset(ap_wall)
   capsule(ap_w+2*ap_clear,ap_d+2*ap_clear);
  translate([0,0,ap_floor]) linear_extrude(ap_collar+0.1)
   capsule(ap_w+2*ap_clear,ap_d+2*ap_clear);
  // Existing provisional cable-body opening: 18 x 10, R2.
  translate([-9,-5,-0.1]) linear_extrude(ap_floor+0.2) rounded_rect(18,10,2);
 }
}
if(part=="front_frame") front_frame();
if(part=="side_gauge") side_gauge();
if(part=="plan_gauge") plan_gauge();
if(part=="airpods_charge_test") airpods_charge_test();

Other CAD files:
src/stl/v0.5/insert_v5.stl
src/stl/v0.5/led_carrier.stl
src/stl/v0.5/fan_mount_test.stl
src/stl/v0.5/rear_carrier.stl
src/stl/v0.4/otr620_vnl_v0_4.scad
src/stl/v0.5/otr620_vnl_v0_5.scad
src/stl/v0.5/airpods_charge_test.stl
src/stl/v0.5/bolt_cover_test.stl
src/stl/v0.5/bolt_head_fit_test.stl
src/stl/v0.5/control_outline_test.stl
src/stl/v0.5/faceplate_v5.stl
src/stl/v0.5/fan_plenum_print_test.stl
src/stl/v0.5/nut_test.stl
src/stl/v0.5/ring_depth_test.stl
src/stl/v0.5/shelf_v5.stl
src/stl/v0.5/side_gauge_plus10.stl
src/stl/v0.5/zero_cover.stl

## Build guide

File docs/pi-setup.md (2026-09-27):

# Pico first, Linux Zero later

Updated 2026-09-27. [Hardware plan](hardware-v0.5.md) · [Tasks](todo.md) · [Existing simulation](../src/pi/README.md)

The current choice is a **Pico 2 WH for local control**, with a **Pi Zero 2 W** added later for a full OS. This supersedes the earlier Zero-only controller plan. `src/pi/` remains a Linux/Python simulation and is not firmware that can be flashed onto a Pico. No live hardware adapter or Pico firmware is implemented by the v0.5 CAD revision.

## Responsibilities

| Device / circuit | Planned responsibility |
|---|---|
| Pico 2 WH | Hardware fan PWM, tach counting, identified temperature sensor, LED dimming, debounced switches and local display |
| Separate power hardware | Regulation, protected load current, USB-C input/output behavior, load switching and power hold-up |
| Future Pi Zero 2 W | OS, SSH, network status, logging, maps, GNSS integration and home-display service |

The Pico must continue its local control policy when the Zero is absent, booting, shut down or disconnected. Network/display activity must not block fan updates. The Freenove board is a GPIO breakout, not the power regulator for the GPS or Zero.

## Proposed Pico pin reservation

This is a planning map using **GPIO numbers**, not physical header pin numbers or a ready-to-wire schematic. Confirm the selected modules and electrical interfaces before connecting them.

| GPIO | Reserved role |
|---|---|
| GP0 / GP1 | UART TX / RX to future Zero, using a common 3.3 V-compatible interface |
| GP4 / GP5 | I²C SDA / SCL for chosen display/module |
| GP6 | Temperature bus, if a compatible 1-Wire sensor is selected |
| GP10 | LED driver dimming request |
| GP12 | Fan hardware PWM request through the verified interface |
| GP13 | Fan tach input through its 3.3 V-compatible interface |
| GP14 | LED switch/button |
| GP15 | Fan auto/boost switch/button |
| GP16 | GPS switch state |
| GP17 | Master/shutdown request input |
| GP18 | GPS load-switch enable request |
| GP19 | Future Zero power enable request |
| GP20 | Future Zero shutdown-ready input, if that scheme is chosen |

A GPIO request cannot carry the GPS/fan/computer load. Keep the fan's regulated supply distinct from the PWM signal. Use the [selected four-pin fan connection plan](hardware-v0.5.md#fan-wiring-and-behavior). Verify PWM waveform, duty, startup and tach readings on the bench before connecting the Garmin.

## Firmware work still needed

1. Choose the supported Pico 2 W MicroPython build or C/C++ SDK and record its version. Recheck official instructions when doing the installation.
2. Implement bounded periodic control, hardware PWM and a watchdog. Start with the host simulation's tested policy as a reference, not a copy of its Linux code.
3. Acquire the identified temperature sensor with timeouts and explicit missing/CRC/stale faults. Never substitute 0°C for an error. A housing sensor is not the GPS battery's internal temperature.
4. Apply auto/boost control and fault priority. The earlier 35°C start, 32°C stop and 35–45°C ramp are bench proposals, not validated protection limits. Calibrate minimum stable duty and restart behavior with the real fan.
5. Debounce inputs and implement dim LED control. Make requested states distinct from measured power or RPM; absent feedback is unknown.
6. Add the selected OLED after control works. Display temperature, fault state, duty, optional RPM and switch state. A missing display must not halt cooling.
7. Add a bounded, versioned UART protocol with sequence numbers, timeouts and status/error replies. A stale host command must not defeat the local fallback policy. Do not make cooling depend on Wi-Fi.
8. Test boot/reset, missing sensor, stuck output, fan stall, disconnected host and recovery. Confirm the fan interface's electrical default state independently of firmware.

Programming USB access is intended with the rear carrier removed. Prevent backfeeding a USB host when an external supply is connected; follow the Pico datasheet's power arrangements. Measure the complete Freenove/Pico/header stack before installing it behind the GPS. Wi-Fi performance near the GPS and metal fasteners remains to test.

## Existing Linux simulation

Run with Python 3.11+; it imports no GPIO library and supports simulation only:

```sh
cd src/pi
python3 -m truck_gps --config config.example.toml --format json
python3 -m unittest discover -s tests -v
```

The existing package provides configuration validation, captured-sample parsing, fan hysteresis, auto/boost policy, LED requests, typed sensor faults, scenario playback and text/JSON output. Its example systemd unit deliberately denies device access. The earlier implementation recorded 21 passing software tests; this CAD revision does not add a physical hardware test claim.

Keep those pure policy tests when adapting behavior to the Pico, and add meaningful firmware/interface tests for timing and failure behavior. A future Linux package should consume Pico status rather than competing to drive the same fan/switch lines. Do not install `RPi.GPIO.PWM()` expecting that function to produce hardware PWM just because a PWM-capable pin was chosen.

## Future Zero bring-up

Install a currently supported Raspberry Pi OS Lite image using official setup guidance, configure SSH/network access, and start on a suitable bench supply. The Zero's native power connector is micro-USB. Its OS storage and power-down process differ from the Pico's firmware environment.

Run the simulation, then implement the Pico protocol client and logging. Add network/Tailscale status with timeouts. Keep credentials out of this repository. Define a shutdown request, confirmation, hold-up interval and load-switch circuit before using ignition/master power to disconnect Linux. A capacitor alone is not a shutdown controller.

Later, select an external GNSS receiver unless a usable Garmin live-position interface is verified. Implement stale/no-fix handling, timestamped tracks, distance calculations, year boundaries and storage retention before adding a home map or traffic API. Keep local logs useful during network loss. Existing API-price notes must be rechecked at implementation time.

## References

- [Pico 2 W datasheet](https://datasheets.raspberrypi.com/picow/pico-2-w-datasheet.pdf)
- [Pico-series official documentation](https://www.raspberrypi.com/documentation/microcontrollers/)
- [Zero 2 W product](https://www.raspberrypi.com/products/raspberry-pi-zero-2-w/)
- [Pi OS setup](https://www.raspberrypi.com/documentation/computers/getting-started.html)
- [Hardware choices and manufacturer sources](hardware-v0.5.md)

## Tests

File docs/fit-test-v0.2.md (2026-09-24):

# v0.2 fit results and v0.4 follow-up

[Project](../README.md) · [Master tasks](todo.md) · [Pi setup](pi-setup.md) · [Parts list](parts-list.md)

Updated September 22, 2026 with the user's photos and measured correction. This record concerns the actual v0.2 pieces; it does not establish fit of the newer external tabs, M2 hardware or complete assembly.

## Reported results

| Feature | User report | v0.4 action |
|---|---|---|
| Front frame | Fits well | Preserve 164.5 × 98.0 mm opening envelope and front profile |
| SIDE gauge rear step | Rear needs to come up **10 mm**, confirmed measured | Raise the rear lower roof/step by 10 mm in both gauge and insert; keep depth, floor and front unchanged |
| Front of SIDE gauge | Front is acceptable; rear contact with rubber lip affects seating | No front tilt/height change; remove rubber if necessary before tightening |
| Dash bolt | Shank passes, head pocket needs enlargement | Preserve 7 mm bore; supply labeled 10.6–12.2 mm head coupons and a **provisional 10.8 mm** insert |
| AirPods with Latercase | Snug fit in the v0.2 collar | Preserve nominal 64.2 × 23.8 mm stadium opening and 12 mm collar wall; add a bottom USB-C opening |
| Charging | Wired bottom access selected | Trial 18 × 10 mm opening; verify actual plug and elbow using the small cup |
| Existing ball mount | Will be removed after the new mount is ready | No ball-mount clearance added |
| TOP gauge / PopSocket | No separate measured result supplied | Keep taper and PopSocket geometry provisional |

Print the three small [v0.4 tests](../src/stl/v0.4/README.md) before the large parts. Bolt-head width, cable-body dimensions and reprinted-part fit remain unmeasured.

Earlier software review baseline: commit `e825f1b328b1a2e486c40cde8956fd3944a4d090`. PR #3 is merged. The current Pi files match the reviewed source, and all 21 software tests pass on Linux/Python 3.12.14. That verifies simulation behavior, not Pi installation, electrical operation, fit or road durability.

## Bring to the truck

- All four prints, with the two depth gauges and two accessory test pieces kept identifiable.
- Calipers if available, a ruler, the intended dash bolt/nut/washer hardware, the AirPods with Latercase and the PopSocket.
- The rubber roll or a measured sample, and the intended right-angle USB-C cable if available.
- Phone camera, removable labels and a pen. Take measurements before sanding or adjusting the parts.

Let prints cool, remove support/brim residue that interferes with seating, and record any elephant foot or warping. Do the fit checks while parked. These tests do not require drilling or final assembly.

## The four files

Nominal dimensions below are derived from the committed [v0.2 OpenSCAD source](../src/stl/v0.2/otr620_vnl_insert.scad), not measurements of the printed parts. Print at 100% scale. Measure the print as well as the truck so printer error is not mistaken for a CAD error.

| File / pieces | Nominal geometry | Check and record | What it cannot prove |
|---|---|---|---|
| `fit_test_1_face_frame.stl` | Outer frame 164.5 × 98.0 mm; GPS pocket 153.8 × 87.8 mm; approximately 4 mm deep | Fit at the front opening; corner/lip interference; left/right/top gaps; whether it sits level without force | Full-depth fit, rear features, GPS fit without the actual unit, or v0.3 external tabs |
| `fit_test_2_depth_gauges.stl` — TOP gauge | Plan outline: 164.5 mm front width, 156.5 mm rear width, 50.8 mm depth | Front-to-rear taper and depth; place the FRONT edge at the cubby front reference; record where it stops and the actual width at that depth | Rounded internal corners, local ribs or the full three-dimensional insert |
| Same file — SIDE gauge | Front height 98.0 mm; front-to-back 50.8 mm; upper step at 24.4 mm depth | Floor reference, upper bar, roof and back wall; test near both sides where accessible; record front protrusion and first contact | Side-wall taper or complete cable/electronics clearance |
| `fit_test_3_bolt_trap.stl` | 7.0 mm shank passage, 10.3 mm hex across flats, 12.0 mm bearing-seat-to-back distance | Bolt head seats fully without spinning; shank slides through; measure actual head, shank and usable thread beyond the coupon | M2 faceplate nut/screw fit, actual dash wall thickness or complete shelf joint strength |
| `fit_test_4_shelf_pockets.stl` — AirPods collar | Inner stadium outline 64.2 × 23.8 mm; collar height 12 mm | Slide over the cased AirPods gently; note tight axes, rocking, seam/button interference and removal effort | The v0.3 upward-facing tray footprint, case height, lid opening, charging access or bump retention |
| Same file — PopGrip seat | Default round recess diameter 59.5 mm, depth 3 mm | Record which PopSocket you own and measure its full base length/width/thickness | The oval PopSocket fit or magnetic retention; the old round seat is not an acceptance test for the oval part |

The frame's nominal cubby clearance is 0.30 mm per side and 0.40 mm at the top. A small deliberate gap is expected; the target is easy seating without binding, not a forced interference fit. Confirm the cubby height is measured from the **top of the black front floor lip** to the opening top. Measuring from lower surrounding trim changes the reference and can invalidate the height.

## Record results

| Item | Measured print size | Truck/accessory measurement | Fits / tight / loose / stops short | Photo / notes |
|---|---|---|---|---|
| Face-frame width and height | | | | |
| Front floor lip / opening corners | | | | |
| TOP gauge, front and rear widths | | | | |
| SIDE gauge, depth and upper bar | | | | |
| Dash bolt head, shank and projection | | | | |
| AirPods width, depth and height with Latercase | | | | |
| PopSocket base length, width and thickness | | | | |

Record printer/filament/nozzle/layer height, slicer scale, supports, print orientation and any cleanup. Photograph the frame straight-on, both gauges in place, and any contact point with a ruler in view. Use the driver's view when labelling left/right. If a gauge binds, record how far its FRONT edge remains proud instead of forcing it.

For a loose fit, record the gap on each side separately. For a tight fit, distinguish a local corner or print defect from the whole width/height being wrong. Adjust measured CAD parameters later; do not globally rescale the model because that also changes bolt holes and hardware pockets.

Bolt length must be chosen using the measured dash wall plus the printed bearing stack, washers, nut and required thread engagement. The 12 mm coupon stack is not a recommendation for a 12 mm bolt. The large dash bolts and small M2 faceplate screws are separate fastener systems.

## What the review leaves unresolved

| Priority | Finding | Next action |
|---|---|---|
| Before the full assembly print | Passing v0.2 does not validate the v0.3 faceplate tabs. Those extend the nominal overall width from 164.5 to 176.5 mm. | Check surrounding trim and print the v0.3 tab/nut coupons after cubby measurements are recorded. |
| Before printing the v0.4 insert | The 10.3 mm v0.2 head trap failed; v0.3 is smaller at 9.9 mm. The v0.4 10.8 mm choice is provisional. | Use the labeled v0.4 head coupons; retain the 7 mm bore that passed. Change `head_af` and re-export if a different coupon fits best. |
| Before adding electronics | The current sound-window height is 39.4 mm. The selected fan body is 40 × 40 × 20 mm, or 22 mm thick with pads. | Treat a fan inside that unchanged window as unproven; design a separate carrier/air path and check the whole installation envelope. |
| Before fixing the fan location | Nominal rear duct depth is only 29.8 mm, calculated as 50.8 − 2.0 back wall − 19.0 GPS pocket depth. | Include GPS rear protrusions, USB elbow, mounting hardware, fan connector, bends and airflow space in the layout. Body thickness alone is insufficient. |
| Before adding holes near the shelf joint | The original tongue-channel roof has about 1.3 mm of nominal plastic beneath the GPS pocket: 6.6 − 5.3 mm. This is a geometry observation, not a strength result. | Keep new cable slots/fasteners away from this bridge until the section and load path are reviewed. |
| Before accepting the shelf | v0.2 collar/round-seat tests do not validate the newer tray orientation, oval pocket or the user's retrieval motion. | Check the v0.4 charging cup, oval PopSocket seat and shelf reach (about 82 mm forward and 74 mm below the cubby). |
| When the GPS arrives | Housing thickness, faceplate overlap, rear ports and gasket compression remain assumptions. | Measure the device and plugged-in cable; verify the faceplate bears on housing and clears glass, controls and ports. |
| Before powering physical hardware | The Pi controller is simulation-only. The default curve does not establish fan startup/minimum duty or fault behavior. | Select the GPIO/PWM interface, test live sensor acquisition and calibrate actual fan behavior on the bench. |
| Before combining supplies | GPS demand, AirPods charging demand, wiring losses and Linux power-hold/shutdown are unresolved. | Keep initial Garmin power separate; complete a measured power budget before selecting shared distribution hardware. |

Fan dimensions are recorded with manufacturer references in [the existing fan plan](pi-setup.md#selected-fan-and-proposed-interface). The 39.4 mm and 29.8 mm values are calculated from CAD. They do not establish available installed airflow clearance.

## Useful work before the Pi or GPS arrives

1. **Component measurement list:** record exact part numbers and envelopes for the Pi/header/connectors, fan, OLED, switches, USB panels and angled cables. Keep unresolved selections blank instead of designing permanent holes around guesses.
2. **Bench wiring plan:** define separate power branches, removable connectors, LED driver/resistors, temperature-sensor placement and the fan signal interface. Final regulator/fuse sizing waits for the verified loads and wiring.
3. **Software next step:** implement bounded live 1-Wire acquisition behind an adapter, with tests for missing files, invalid samples and old readings. Keep hardware outputs disabled until the actual board/OS and wiring are verified.
4. **Serviceability plan:** reserve access to the microSD card, screws, GPS power button and cable connectors. An electronics carrier should come out without breaking the GPS support or permanent wiring.
5. **Charging sequence:** verify wired AirPods access first. A removable wireless charger can follow after the actual puck, case alignment and temperature behavior are tested; an exposed shelf alone does not validate temperatures.

The reported +10 mm rear correction is implemented in [v0.4](../src/stl/v0.4/README.md); earlier revisions are preserved. Mesh checks and limited CAD intersection checks pass. Physical fit of the new files, bolt-head selection, cable access and the complete assembly still require the follow-up tests.

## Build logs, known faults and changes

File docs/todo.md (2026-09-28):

# Build tasks

Updated 2026-09-27. [Current fit tests](../src/stl/v0.6/README.md) · [Parts](parts-list.md) · [Hardware](hardware-v0.5.md) · [Software](pi-setup.md)

## Recorded decisions and completed design work

- [x] Record successful v0.2 front-frame, dash-bolt shank and cased-AirPods collar fits.
- [x] Archive the earlier rear +10 mm correction; superseded by the confirmed 80 mm rear clearance.
- [x] Record 170 mm inside width, 98 mm front height, 80 mm rear height and 64 x 49 x 24 mm cased AirPods.
- [x] Export v0.6 front, side, plan and AirPods charging fit coupons.
- [x] Supply bolt-head sizing coupons; retain **10.8 mm as a trial**, not a confirmed head fit.
- [x] Retain the upward-facing AirPods collar and bottom charging opening; defer wireless charging.
- [x] Record that the ball mount will be removed and the cubby rubber can be removed if it obstructs seating.
- [x] Record ordered M2 × 6 faceplate screws/nuts and the ESR ring.
- [x] Select **Noctua NF-A4x20 5V PWM, four-pin** after clarifying the linked three-pin variant.
- [x] Change architecture to **Pico 2 WH local control**, with **Pi Zero 2 W Linux host later**.
- [x] Add v0.5 fan/plenum, removable Freenove carrier, upper vents, modular controls, ESR trial recess and shelf modules.
- [x] Provide replaceable blank control and inlet panels without inventing dimensions for unselected modules.
- [x] Preserve earlier source revisions and the existing simulation-only Linux package.

CAD and mesh checks are recorded with the v0.5 files. They do not check off the physical tests below.

## Next print batch

- [ ] Print v0.6 `front_frame.stl`, `side_gauge.stl` and `plan_gauge.stl`; record liner state, notch depth and taper fit.
- [ ] Print v0.6 `airpods_charge_test.stl`; compare retention with the previous snug collar.
- [ ] Rework the full shell, fan/plenum, carrier and screw bosses below the confirmed 80 mm rear height.
- [ ] Regenerate the matching shelf/faceplate for the 169.4 mm printed front width; do not mix widths.
- [ ] Recheck all nominal intersections and stepped-cubby containment after integration.
- [ ] Print `bolt_head_fit_test.stl`; record the selected pocket, real head dimensions, bolt length and thread type.
- [ ] Test the v0.6 `airpods_charge_test.stl` with the cased AirPods and actual angled cable; check lid opening and removal.
- [ ] Test ordered M2 hardware with `nut_test.stl` and `bolt_cover_test.stl`; verify thread engagement and tip clearance.
- [ ] After rear-layout revision, print the regenerated `fan_plenum_print_test.stl` to tune bridges and verify support removal before the full insert.
- [ ] Test `fan_mount_test.stl` with the actual four-pin 5 V fan, pads, screws and washers.
- [ ] After rear-layout revision, print the regenerated `rear_carrier.stl`; confirm Freenove hole size/pattern and actual Pico/header/wire height.
- [ ] Test `ring_depth_test.stl`; measure ring diameter and adhesive thickness, then set recess diameter/depth.
- [ ] After rear-layout revision, use a regenerated packing test and `control_outline_test.stl` to check cubby and left-trim space.
- [ ] Check shelf and module clearance above radio controls with the accessories and cables installed.
- [ ] Record filament, nozzle, scale, slicer profile and all measured outcomes before revising parameters.

## When the GPS arrives

- [ ] Measure actual housing thickness, corner radius and bezel boundary.
- [ ] Locate the speaker, microphone, rear mount socket, power button, microSD and USB-C port from the actual unit.
- [ ] Measure the plugged-in 90° cable body and bend envelope; replace the trial keepout in the CAD.
- [ ] Confirm rubber thickness and compression; test housing retention and removal.
- [ ] Verify the faceplate's 1.2 mm overlap bears on housing, never glass; test the gasket and cure material away from the GPS.
- [ ] Confirm GPS/adapter power ratings and peak demand in navigation/charging use. Do not assume 5 V / 1 A.
- [ ] Verify access for resets and servicing without damage to the mount or connectors.

## Before the full print and installation

- [ ] Resolve head size, ring depth, Pico stack and required fastener adjustments; re-export affected parts.
- [ ] Inspect the insert's new fan plenum/vents in the slicer. Review bridges, accessible supports and removal paths; the old v0.2 support guidance no longer applies.
- [ ] Confirm all print footprints including brim, supports, clips and purge lines on the actual 220 mm bed.
- [ ] Select the final material/profile for cab heat and printer capability; evaluate deformation and pad creep.
- [ ] Assemble the carrier, fan, shell, shelf and faceplate with tested hardware; check pinched wires and PCB insulation.
- [ ] Confirm load spreading and rear access for the owned dash bolts; remove the existing ball mount at installation.
- [ ] Test fan flow through the shallow plenum, compartment temperature, speaker intelligibility, whistling and rattles.
- [ ] If flow is inadequate, enlarge/relocate ventilation or fan before relying on cooling.
- [ ] Test magnetic hold and adhesive strength while preserving easy PopSocket retrieval.
- [ ] Verify GPS reception, microphone performance, charging and accessible radio controls while stationary.
- [ ] Evaluate fastener loosening and retention before relying on the assembly on the road.

## Power and controls

- [ ] Initially run Garmin from its supplied/approved supply and accessories from a separate regulated branch.
- [ ] Select exact OLED, switches, temperature probe and LED packages; measure bodies, holes, plugs and service clearance.
- [ ] Cut the replaceable control panel only after those parts are chosen.
- [ ] Select and bench-test the fan PWM interface, tach input and electrical default behavior.
- [ ] Select LED resistors/driver for dim, indirect blue lighting and a manual off command.
- [ ] Build a measured load budget including future Zero, GPS charging, fan, LEDs and AirPods.
- [ ] Select USB-C input/PD hardware, converter, branch protection and proper USB-C charging-source module.
- [ ] Confirm the selected power circuit fits the reserved module, or replace that module/use an external enclosure.
- [ ] Add a suitable inlet cutout to the removable blank; provide edge protection, strain relief and labelled harnesses.
- [ ] Prevent programming/USB supply backfeed; define common grounds and switching default states.
- [ ] Design Linux shutdown/power hold-up before connecting ignition or a true master cutoff.

## Pico firmware and future Linux host

- [ ] Create a Pico 2 WH firmware project after selecting toolchain/version; existing `src/pi/` is not Pico firmware.
- [ ] Implement hardware PWM, bounded sensor acquisition, tach counting, switch debounce and watchdog handling.
- [ ] Port the useful policy behavior: hysteresis, auto/boost, explicit faults and safe fallback requests.
- [ ] Calibrate fan startup/minimum duty and temperatures on real hardware; proposals are not protection ratings.
- [ ] Add OLED/LED behavior after the control loop works; keep display/network failure independent.
- [ ] Test boot/reset, sensor loss, stuck fan, controller faults and host disconnection.
- [ ] Define and test a versioned bounded Pico–Zero protocol and stale-command handling.
- [ ] Fit the future Zero, actual header/ports and microSD access in the shelf module; revise if needed.
- [ ] Install supported Pi OS Lite and network access; test logging and controlled shutdown on the bench.
- [ ] Verify a live GNSS data source, then implement no-fix handling, track storage, distance and year-boundary logic.
- [ ] Add private home-display access and maps; recheck current API terms/pricing before integration.

Older prompts and rationale remain in [chats.md](chats.md). This active task list supersedes earlier controller and fan choices without treating untested models as completed physical work.

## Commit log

2026-09-23 Add v0.4 measured-fit STL revision and wired AirPods shelf
    Raise the rear step 10 mm, preserve the front opening and shank bore,
    add bolt-head sizing coupons, and retain the tested AirPods collar
    with bottom USB-C access. Record mesh checks and physical test limits.
    [airpods_charge_test.stl, bolt_head_fit_test.stl, faceplate.stl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]
2026-09-27 Add v0.5 fan, Pico carrier and modular shelf fit prototypes
    [airpods_charge_test.stl, bolt_cover_test.stl, bolt_head_fit_test.stl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]
2026-09-28 Add v0.6 caliper fit coupons and supersede rear +10 mm assumption
    [airpods_charge_test.stl, fit_check.scad, front_frame.stl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]
